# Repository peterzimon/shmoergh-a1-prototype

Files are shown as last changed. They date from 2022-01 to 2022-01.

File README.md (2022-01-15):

# Shmøergh A1 — Semi-modular analog monosynth

A1 is a fully analog semi-modular monosynth. I took the Minimoog as my main inspiration for its sound but of course the circuitry is nowhere comparable with it. The synth has a default hardwired patch inside, it has a couple of modulation sources and targets so we can consider it semi-modular. Everything is handmade by me at home. Most of the module circuits are based on very well-known schematics and a few of the circuits are original. 

a1

### Features
- Fat AF analog sound, fun
- Two voices with 3 waveshapes (saw, triangle, pulse) and additional noise and square suboscillator sound sources
- 24dB/oct diode low pass filter with self-resonance and dedicated envelope generator
- Triangle and square waveform LFO
- Mod matrix for overriding default patch
- Follows Eurorack standards: 10Vpp signal and modulation, 0-8V envelope levels
- All modules are designed and built on separate PCBs for reusability and experimenting

### What's in this repo?
You can find all the **KiCad 5** files (schematics and PCB design) of the synth here.

---

### License and disclaimer
All circuits, schematics, printed circuit board, panel design and associated data published within this project can be used for private use only. The author, host, and all people associated with these circuits disclaim any liability for damages should anyone be killed or injured while working on these projects, or projects based on these designs, or any other project or design presented in these schematics. The author, host, and all people associated with these circuits also disclaim any liability for projects, or projects based on these designs, or any other project or design presented on these web pages and any associated web pages when used in such a way as to infringe relevant government regulations and by-laws.

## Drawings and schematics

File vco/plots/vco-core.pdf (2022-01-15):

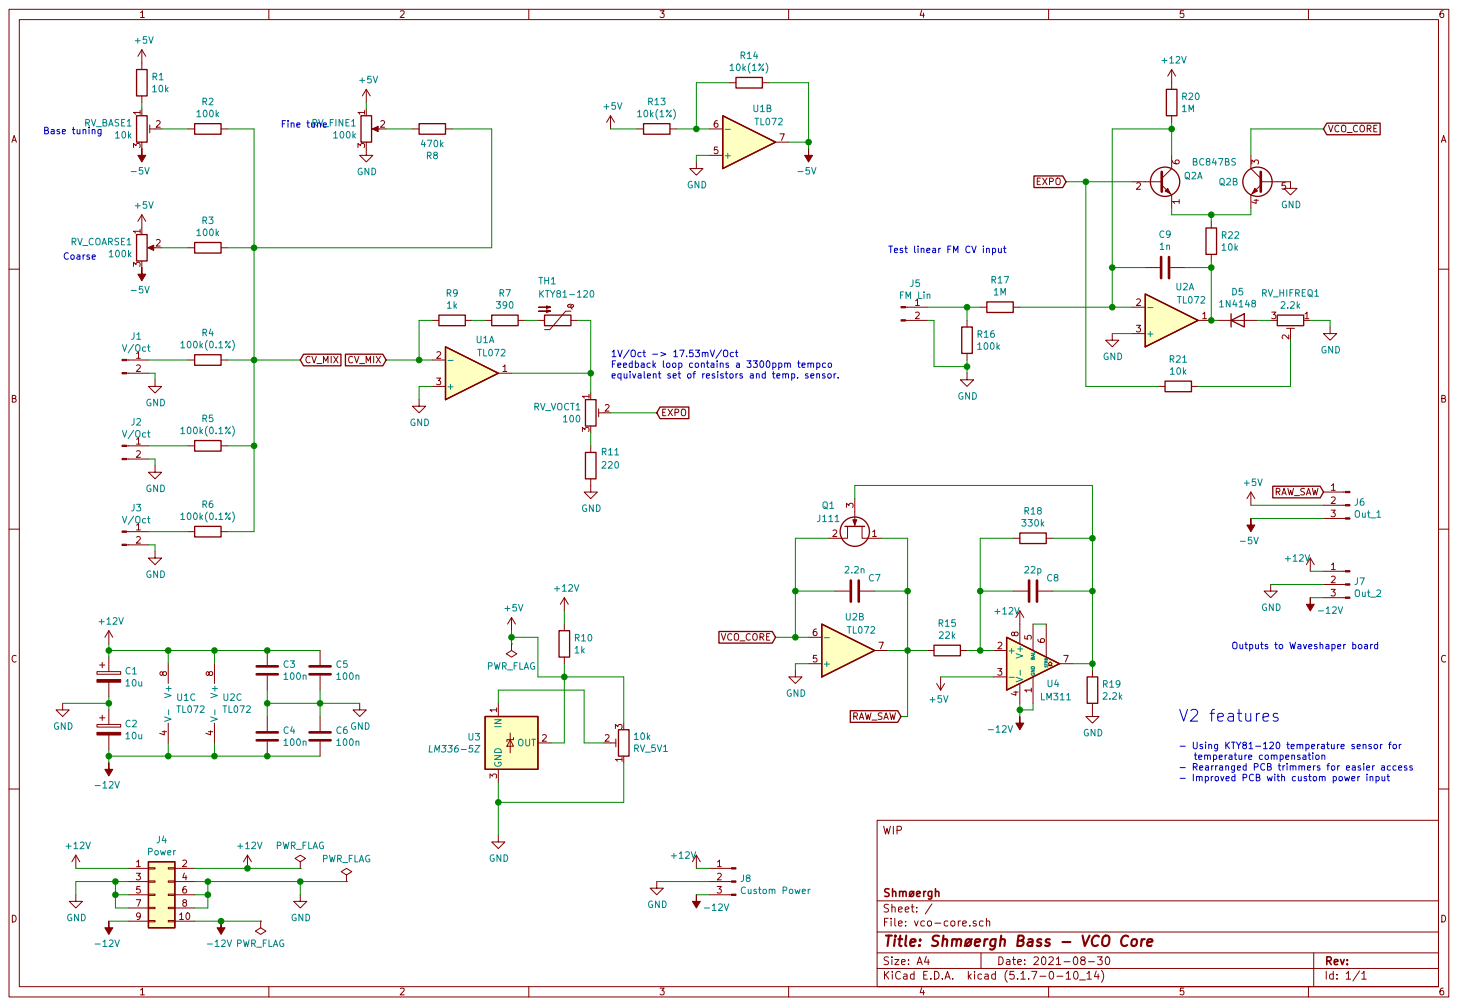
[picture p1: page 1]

1V/Oct -> 17.53mV/Oct Feedback loop contains a 3300ppm tempco
equivalent set of resistors and temp. sensor.
100 GND

- Using KTY81-120 temperature sensor for
temperature compensation
- Rearranged PCB trimmers for easier access
- Improved PCB with custom power input

File: vco-core.sch Sheet: / Shmøergh WIP

Id: 1/1 Title: Shmøergh Bass - VCO Core

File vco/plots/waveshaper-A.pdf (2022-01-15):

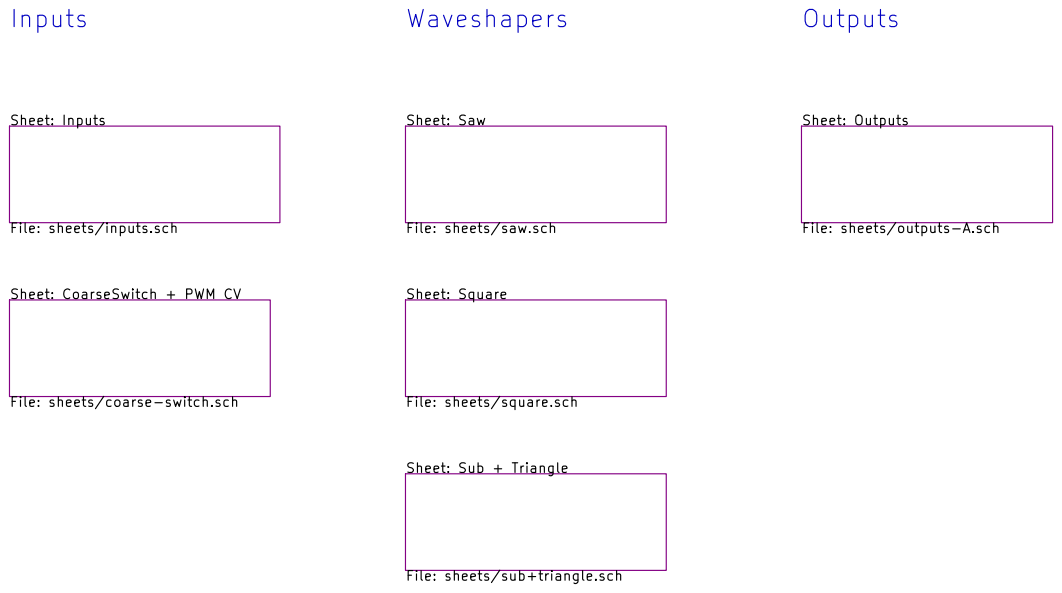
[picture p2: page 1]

File: sheets/coarse-switch.sch Sheet: Inputs

File: sheets/saw.sch Sheet: CoarseSwitch + PWM CV

File: sheets/inputs.sch

File: sheets/outputs-A.sch

File: sheets/square.sch

File: sheets/sub+triangle.sch

File: waveshaper-A.sch Sheet: / Shmøergh WIP

Id: 1/7 Title: Shmøergh Bass - VCO IO + Waveshaper

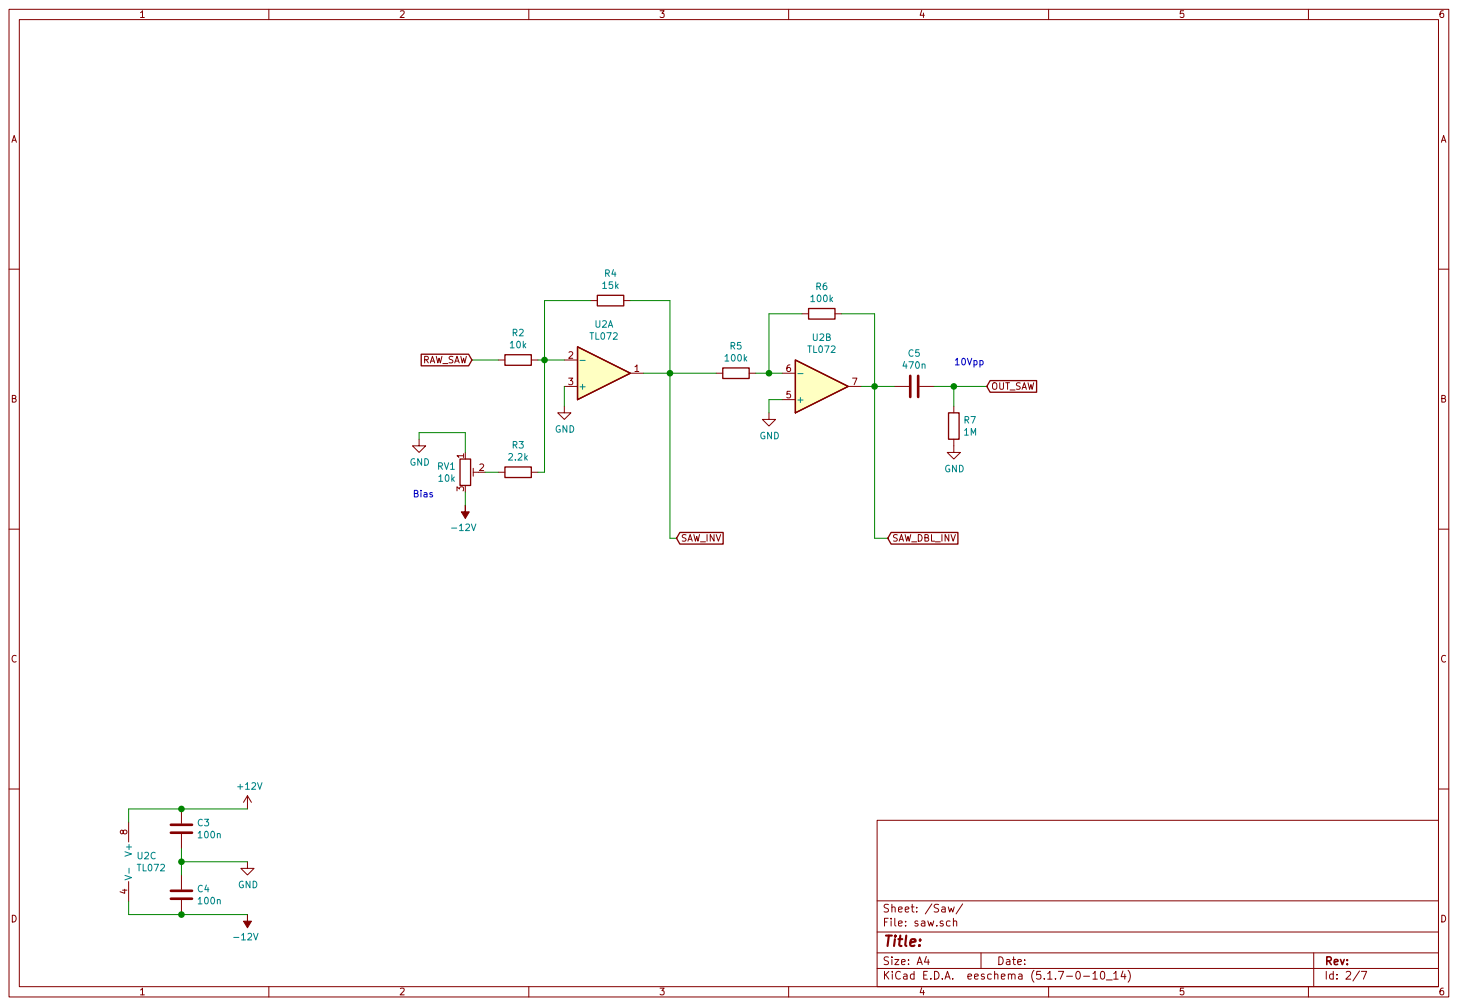
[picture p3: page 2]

Id: 2/7 Title: File: saw.sch Sheet: /Saw/

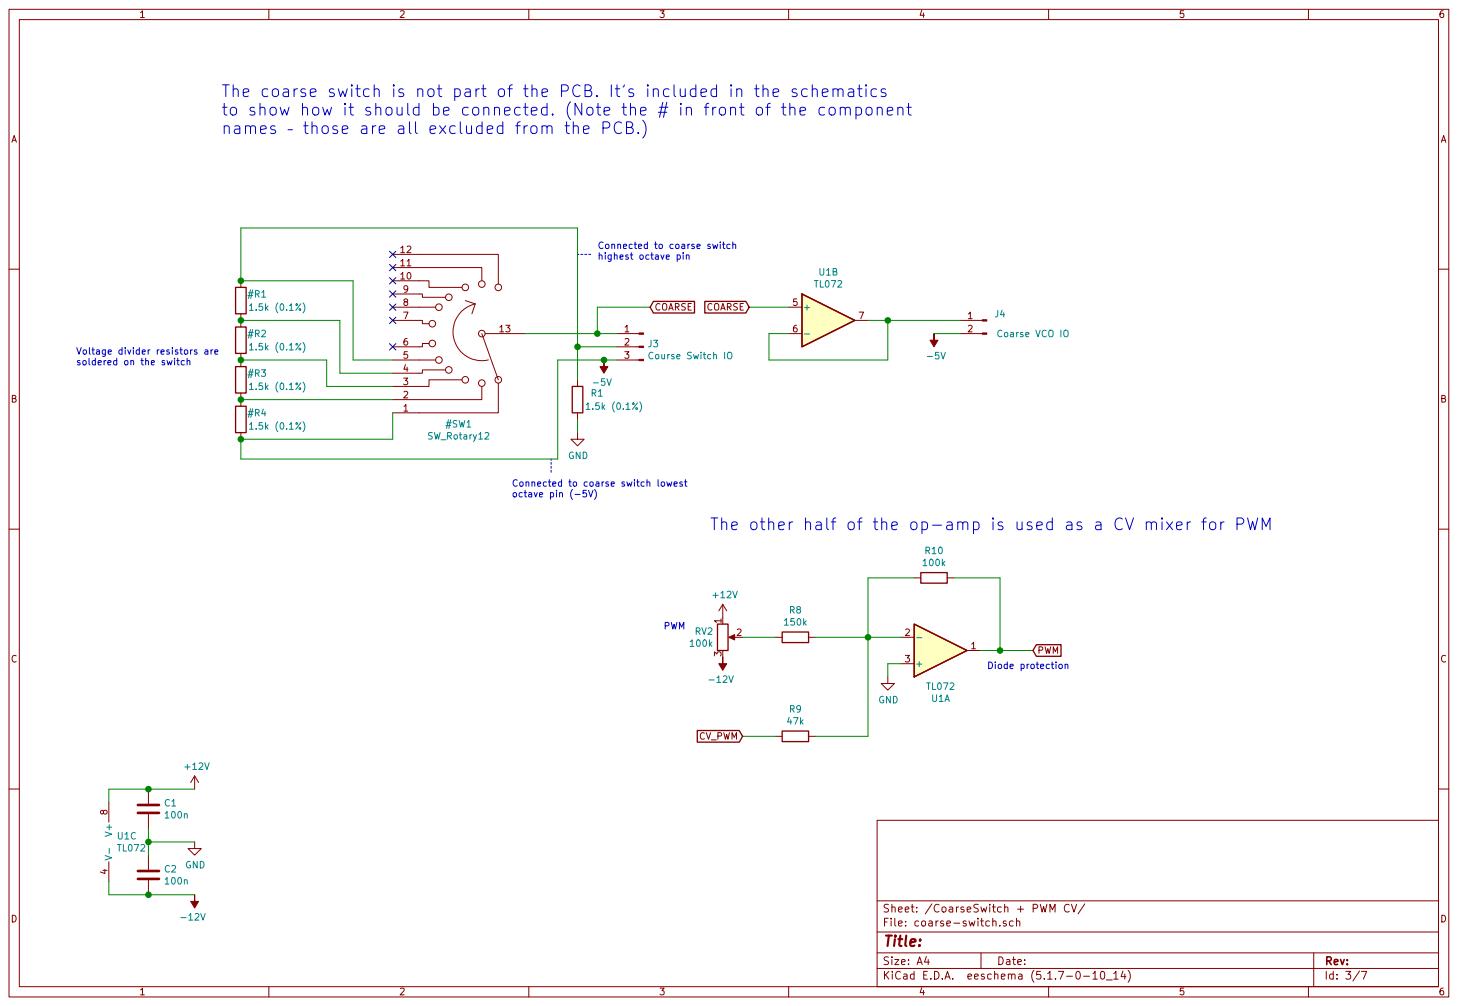
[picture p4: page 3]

The coarse switch is not part of the PCB. Its included in the schematics
to show how it should be connected. (Note the # in front of the component
names those are all excluded from the PCB.)

Id: 3/7 Title: File: coarse-switch.sch Sheet: /CoarseSwitch + PWM CV/

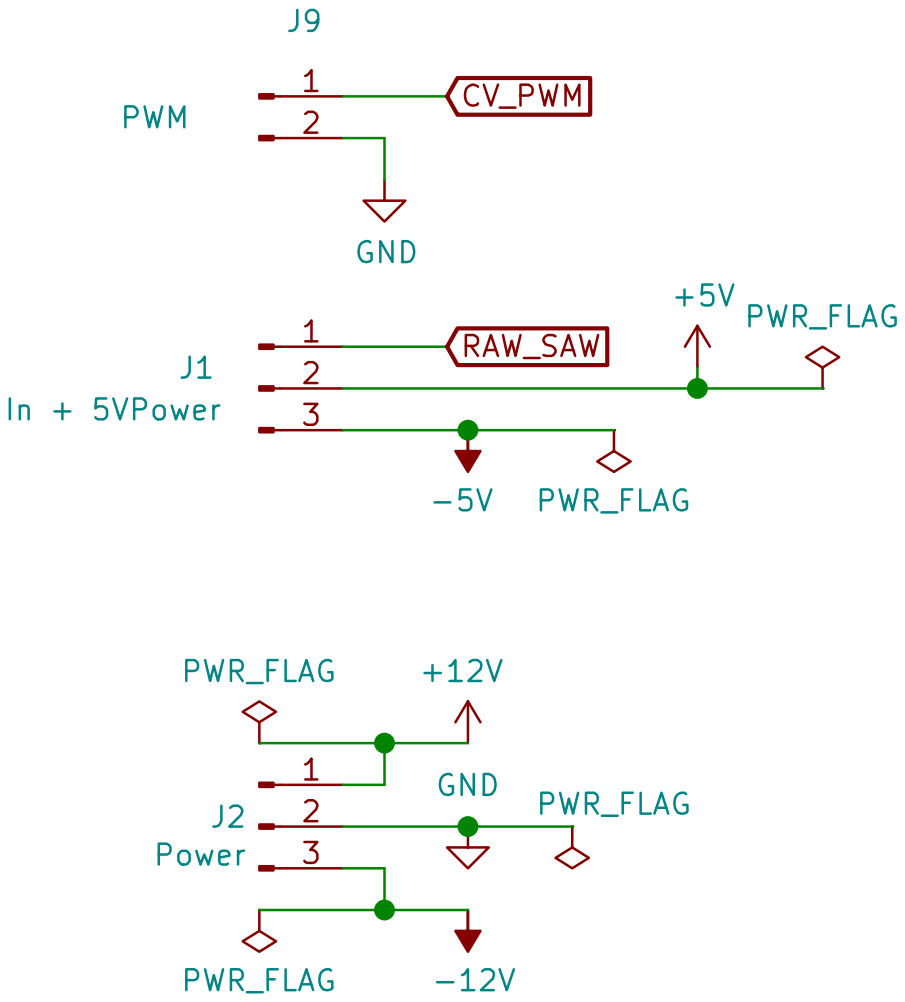
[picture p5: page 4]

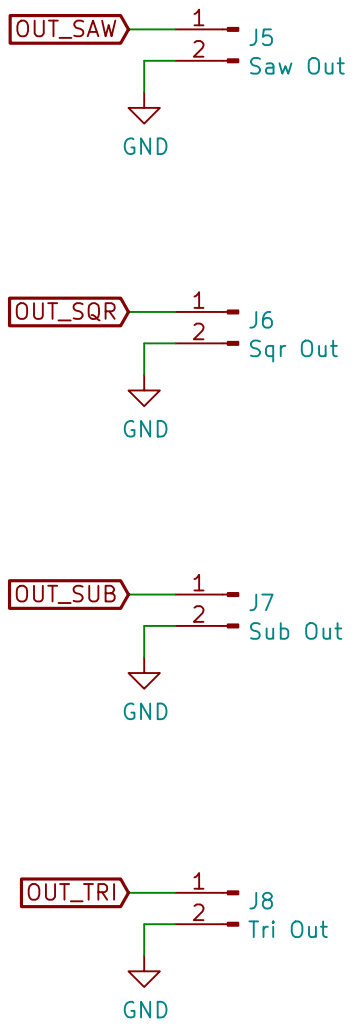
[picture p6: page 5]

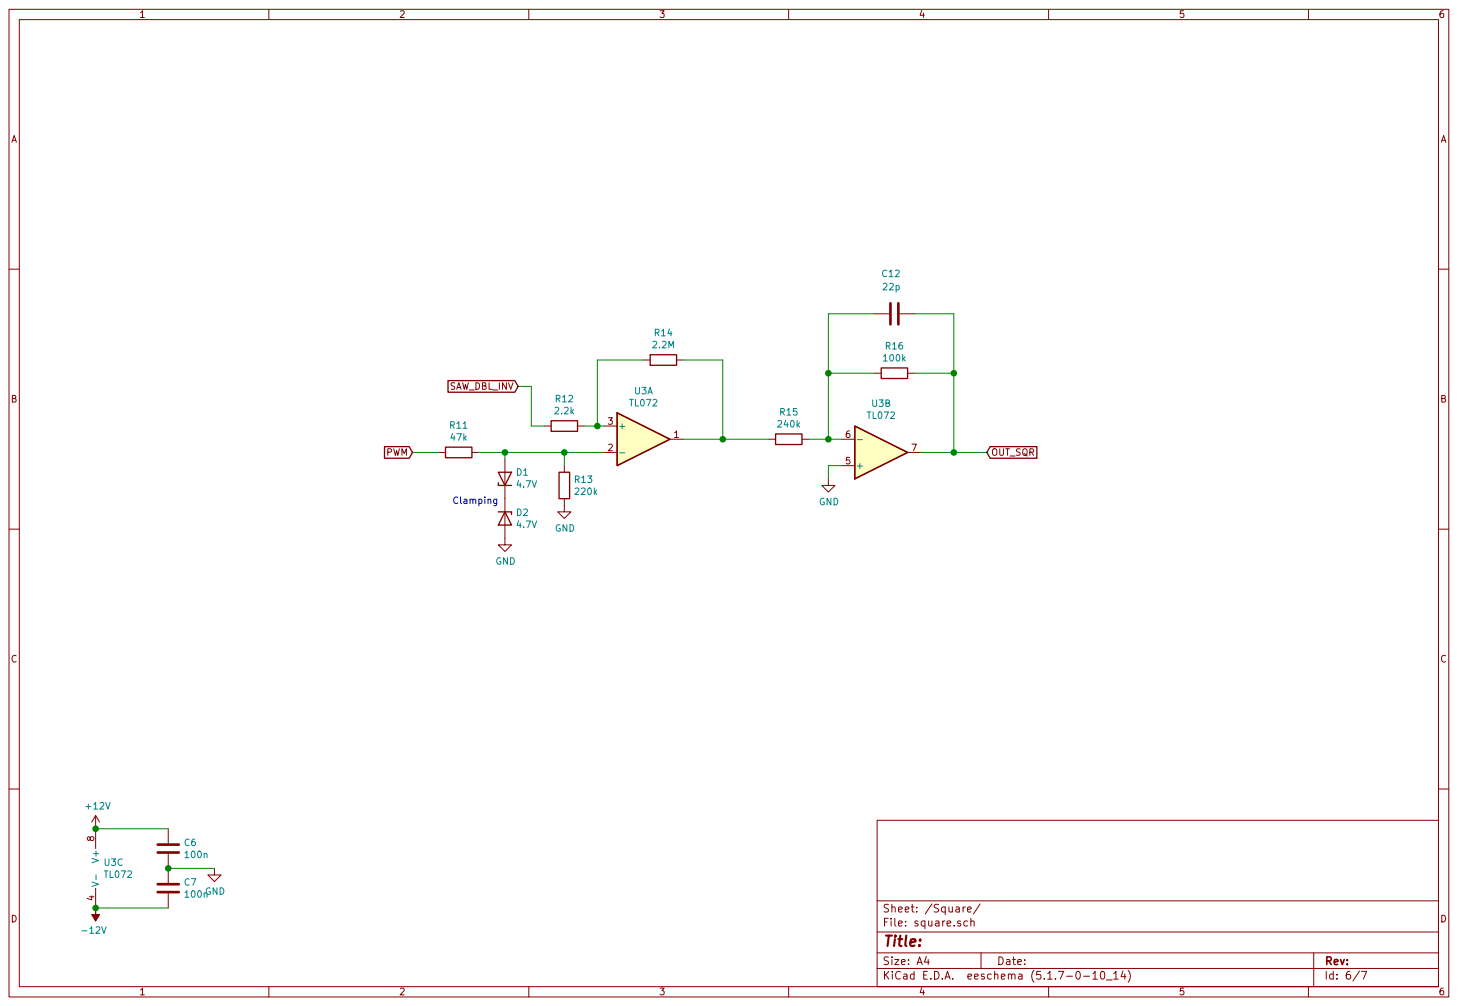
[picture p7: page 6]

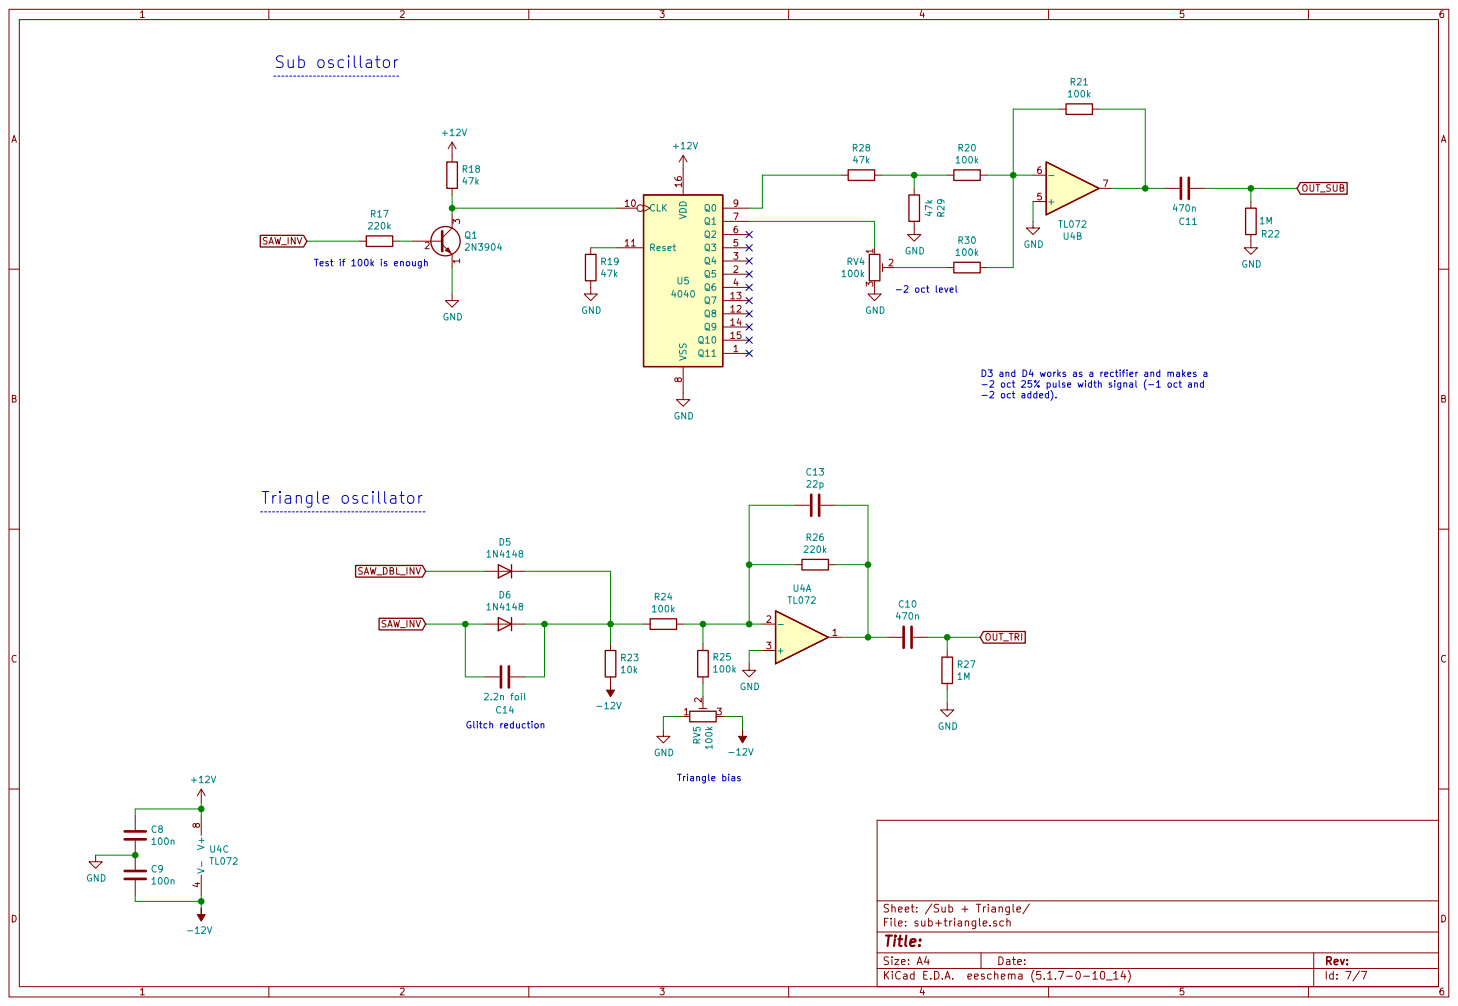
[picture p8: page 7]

Test if 100k is enough

Sheet: /Sub + Triangle/
File: sub+triangle.sch
Id: 7/7 Title:

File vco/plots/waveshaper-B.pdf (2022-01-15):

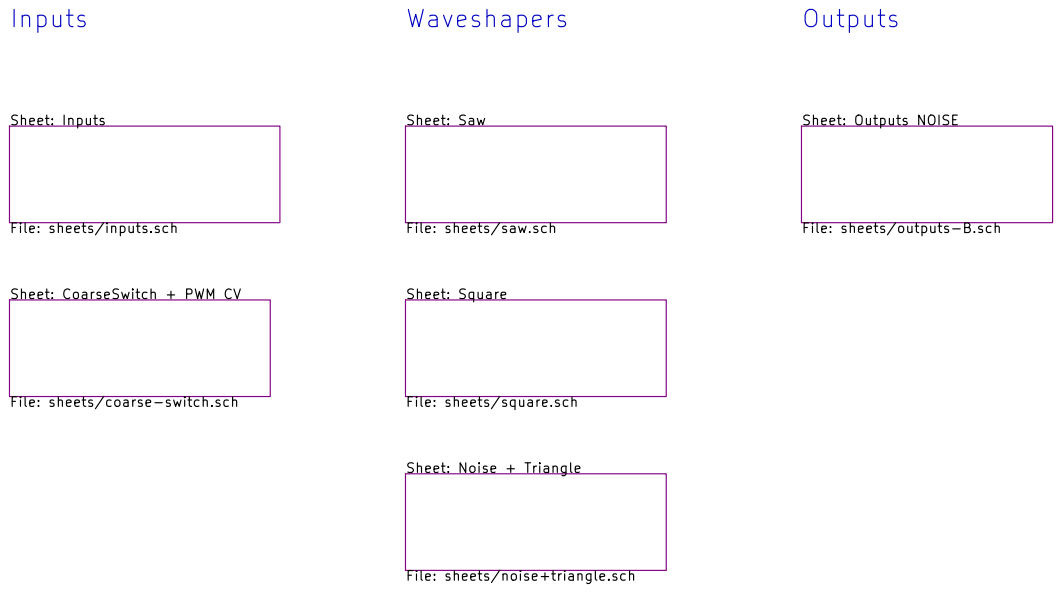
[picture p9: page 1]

File: sheets/coarse-switch.sch Sheet: Inputs

File: sheets/saw.sch Sheet: CoarseSwitch + PWM CV

File: sheets/inputs.sch

File: sheets/outputs-B.sch

File: sheets/square.sch

File: sheets/noise+triangle.sch

File: waveshaper-B.sch Sheet: / Shmøergh WIP

Id: 1/7 Title: Shmøergh Bass - VCO IO + Waveshaper


Id: 2/7 Title: File: saw.sch Sheet: /Saw/


The coarse switch is not part of the PCB. Its included in the schematics
to show how it should be connected. (Note the # in front of the component
names those are all excluded from the PCB.)

Id: 3/7 Title: File: coarse-switch.sch Sheet: /CoarseSwitch + PWM CV/


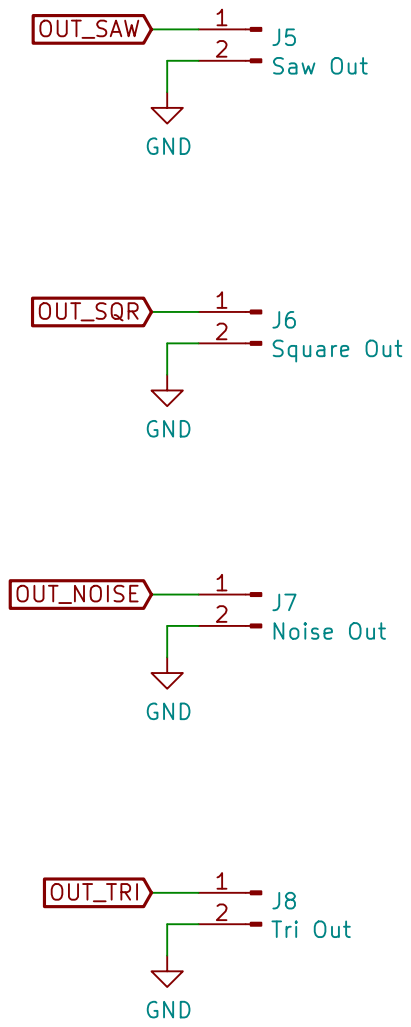
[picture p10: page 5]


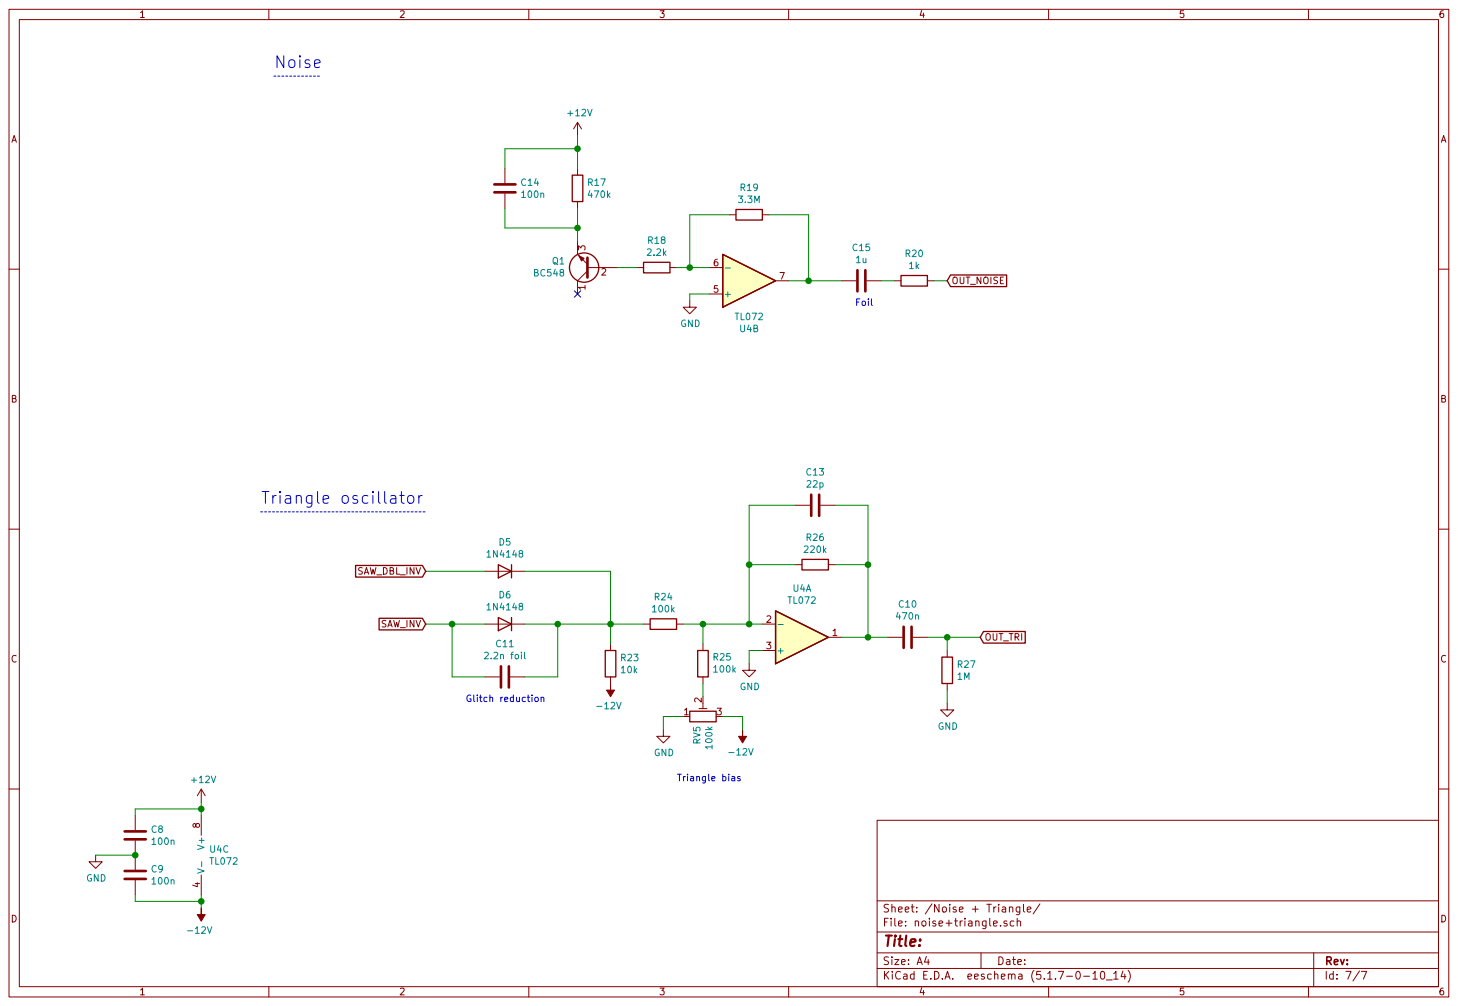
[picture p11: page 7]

File: noise+triangle.sch
Id: 7/7 Title:

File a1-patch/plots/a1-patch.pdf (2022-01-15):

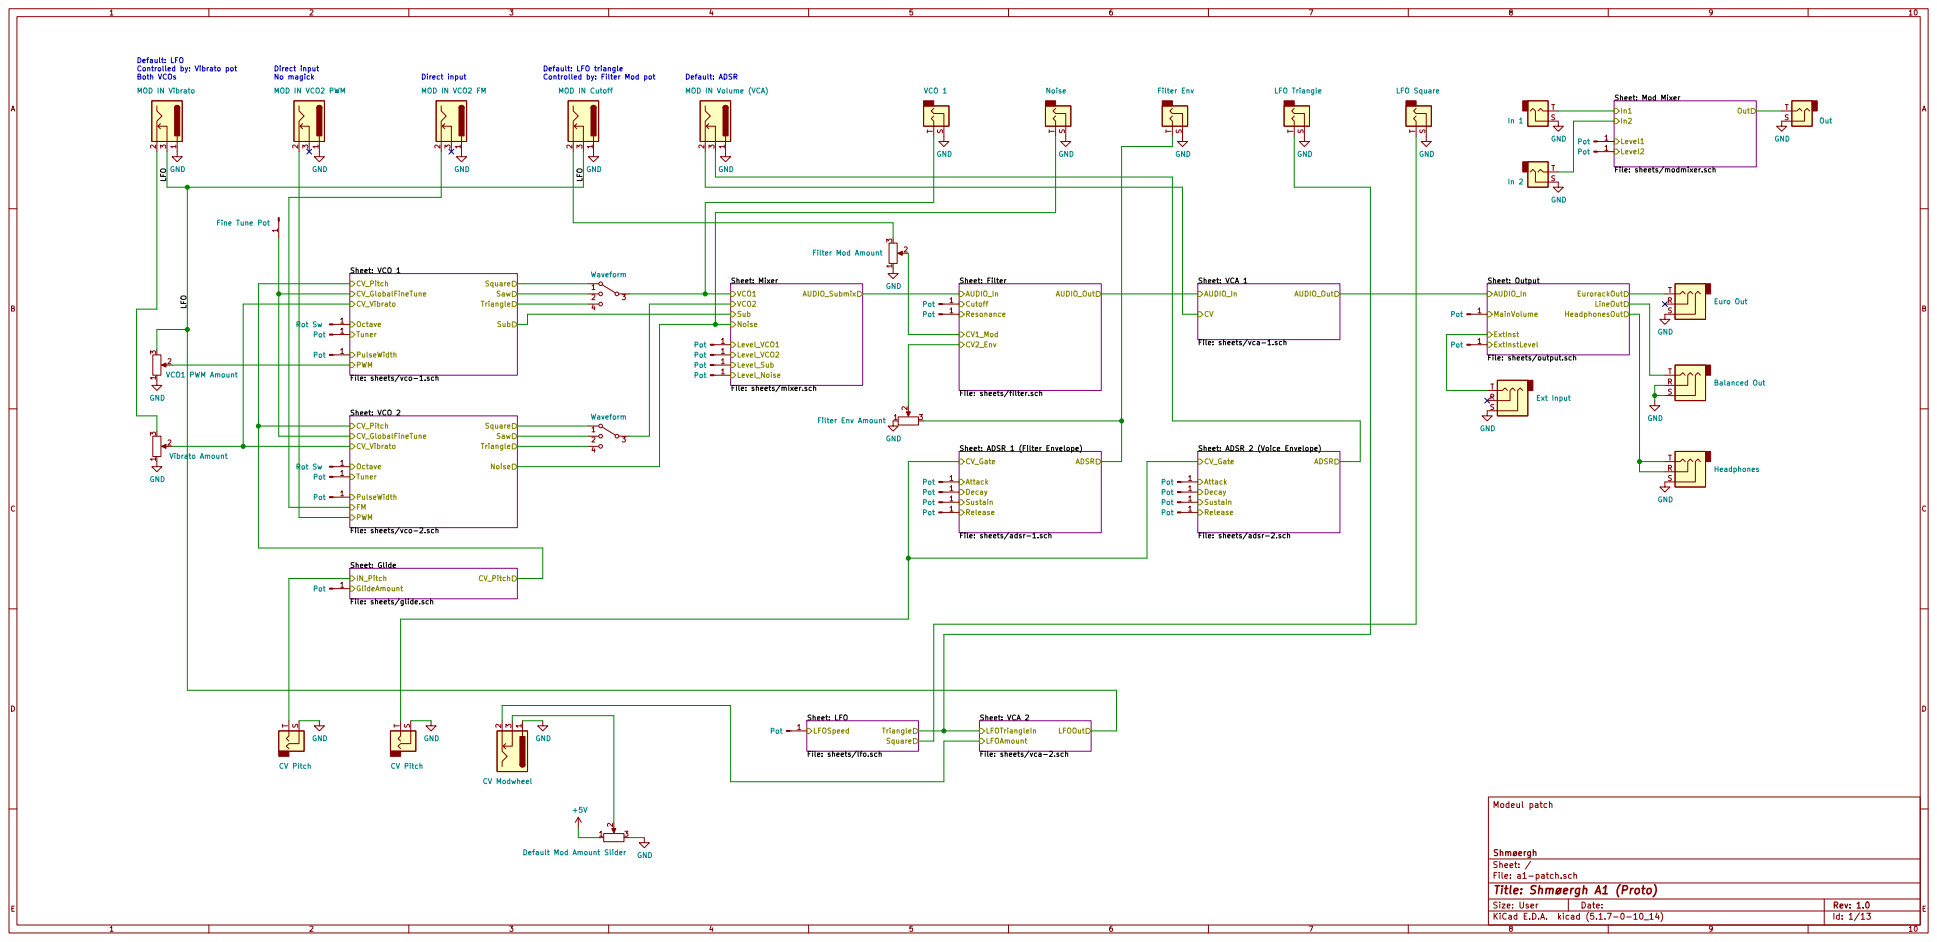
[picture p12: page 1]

Controlled by: Filter Mod pot

1 MOD IN Vibrato GND

1 MOD IN VCO2 FM LFO LFO LFO

1 MOD IN Cutoff GND GNDGND GND

1 MOD IN Volume (VCA) GND

Sheet: Mod Mixer File: sheets/modmixer.sch

3 VCO1 PWM Amount GND GND

3 Vibrato Amount GND GND

3 Filter Mod Amount GND GND GND

3 Filter Env Amount 1 Pot

Square Sheet: Glide File: sheets/glide.sch

Sheet: VCA 2 File: sheets/vca-2.sch

File: sheets/lfo.sch

3 Default Mod Amount Slider

File: a1-patch.sch Sheet: / Shmøergh

Id: 1/13 Title: Shmøergh A1 (Proto)

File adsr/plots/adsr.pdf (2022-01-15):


Id: 1/4 Title: File: adsr.sch Sheet: /


(c) Rene Schmitz - https://www.schmitzbits.de/adsr.html
File: adsr-1.sch Sheet: /ADSR 1/ Shmøergh


File: power.sch Sheet: /Power/
Id: 3/4 Title:


Id: 4/4 Title: File: adsr-2.sch Sheet: /ADSR 2/

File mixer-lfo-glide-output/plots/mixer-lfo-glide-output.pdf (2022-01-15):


Sheet: Power File: sheets/power.sch

File: sheets/inputs.sch

File: sheets/lfo.sch Sheet: Glide File: sheets/glide.sch

File: mixer-lfo-glide-output.sch Sheet: / Shmøergh

Id: 1/7 Title: Mixer + LFO + Glide


File: power.sch Sheet: /Power/
Id: 2/7 Title:


Level pots are wired on panel,
not present on PCB
#RV1 A50k GND

J22 Glide In GND GND


LFO Triangle (VCA) GND


Square narrow pulse width makes the
output center go off 0V. The 10u cap is
most probably not needed, as everything
(except for the external input) is AC
coupled already.

Id: 5/7 Title: File: mixer.sch Sheet: /Mixer/


Output level should be cca. 5V

Id: 6/7 Title: File: lfo.sch Sheet: /LFO/ C12


File: glide.sch Sheet: /Glide/ C15

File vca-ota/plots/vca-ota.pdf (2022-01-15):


connected to modwheel of keyboard.

File: vca-ota.sch Sheet: / Shmøergh A1


File: power.sch Sheet: /Power/
Id: 2/4 Title:


CV from the Mod mixer. This can
either be +/-5V (e.g. LFO or VCO
output) or 0-8V (filter ADSR).
Negative values shouldnt be an
issue because Q1 would be closed
in that case, so the input should be

Id: 3/4 Title: File: vca-1.sch Sheet: /OTA-VCA-1/


or via the modwheel of a controller. LFO VCA

Jack as switch here to enable direct modwheel connection from controller. Transistors reverse bias safety diode

The purpose of this VCA is to be able to controll the
LFO amount via either the mod slider pot on the synth

in case of negative

This is the slider pot on the
frontpanel of the synth. Its
the same purpose as the modwheel on controllers.

Safety resistor, max Iabc = 12V / 6.8k = 1.76mA
(in case transistors collector voltage = 12V)

IOut(pp) = (q/2kT) * Iabc * Vin = 19.2 * 500uA * 61.6mV

Id: 4/4 Title: File: vca-2.sch Sheet: /OTA-VCA-2/

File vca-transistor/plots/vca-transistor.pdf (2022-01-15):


connected to modwheel of keyboard.

File: vca-transistor.sch Sheet: / Shmøergh A1


VCA for the main output. Chain:
VCO > Mixer > Filter > VCA (controlled by ADSR 1) > Out stage

transistors +/-5V Coming from the mod matrix 0-8V Only for VCA 1

Should be around 5.6k Matched

Id: 2/4 Title: File: vca-1.sch Sheet: /VCA-1/


File: power.sch Sheet: /Power/
Id: 3/4 Title:


The purpose of this VCA is to let the modwheel
control the amount of global LFO. Alternatively
theres a slide pot that can be used instead of

transistors Jack as switch here to enable modwheel connection Only for VCA 2

Id: 4/4 Title: File: vca-2.sch Sheet: /VCA-2/

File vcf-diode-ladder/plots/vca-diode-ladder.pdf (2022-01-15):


To be improved: the resonance path
picks up a lot of hum, especially if

RV_RESONANCE pot is connected via wires. To be improved: passive CV mixer to active

File: vca-diode-ladder.sch Sheet: / WIP

Id: 1/1 Title: Schmøergh Analog - Diode Ladder VCF

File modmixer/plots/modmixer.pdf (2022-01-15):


File: modmixer.sch Sheet: / Shmøergh

Id: 1/1 Title: ModMatrix Utilities

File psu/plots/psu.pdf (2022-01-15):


Id: 1/1 Title: Shmøergh Bass PSU


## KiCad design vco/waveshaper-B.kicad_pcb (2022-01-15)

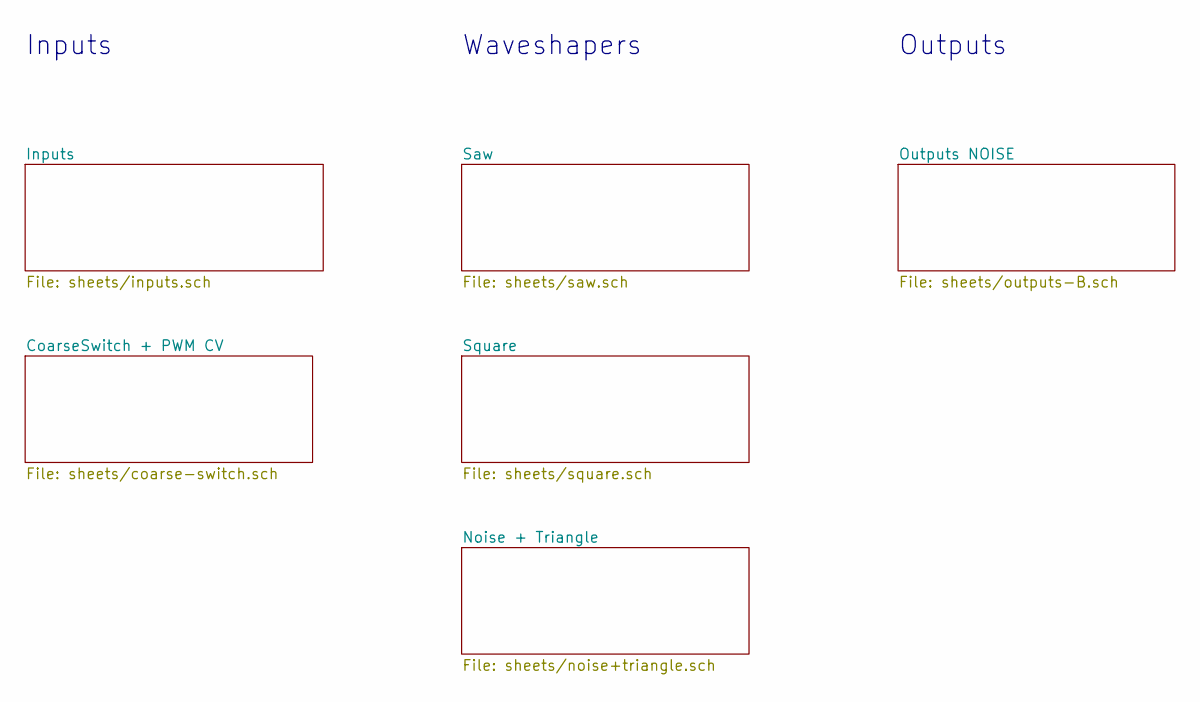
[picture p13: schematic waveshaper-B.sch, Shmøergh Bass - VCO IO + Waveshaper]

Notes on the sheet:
Inputs
Waveshapers
Outputs

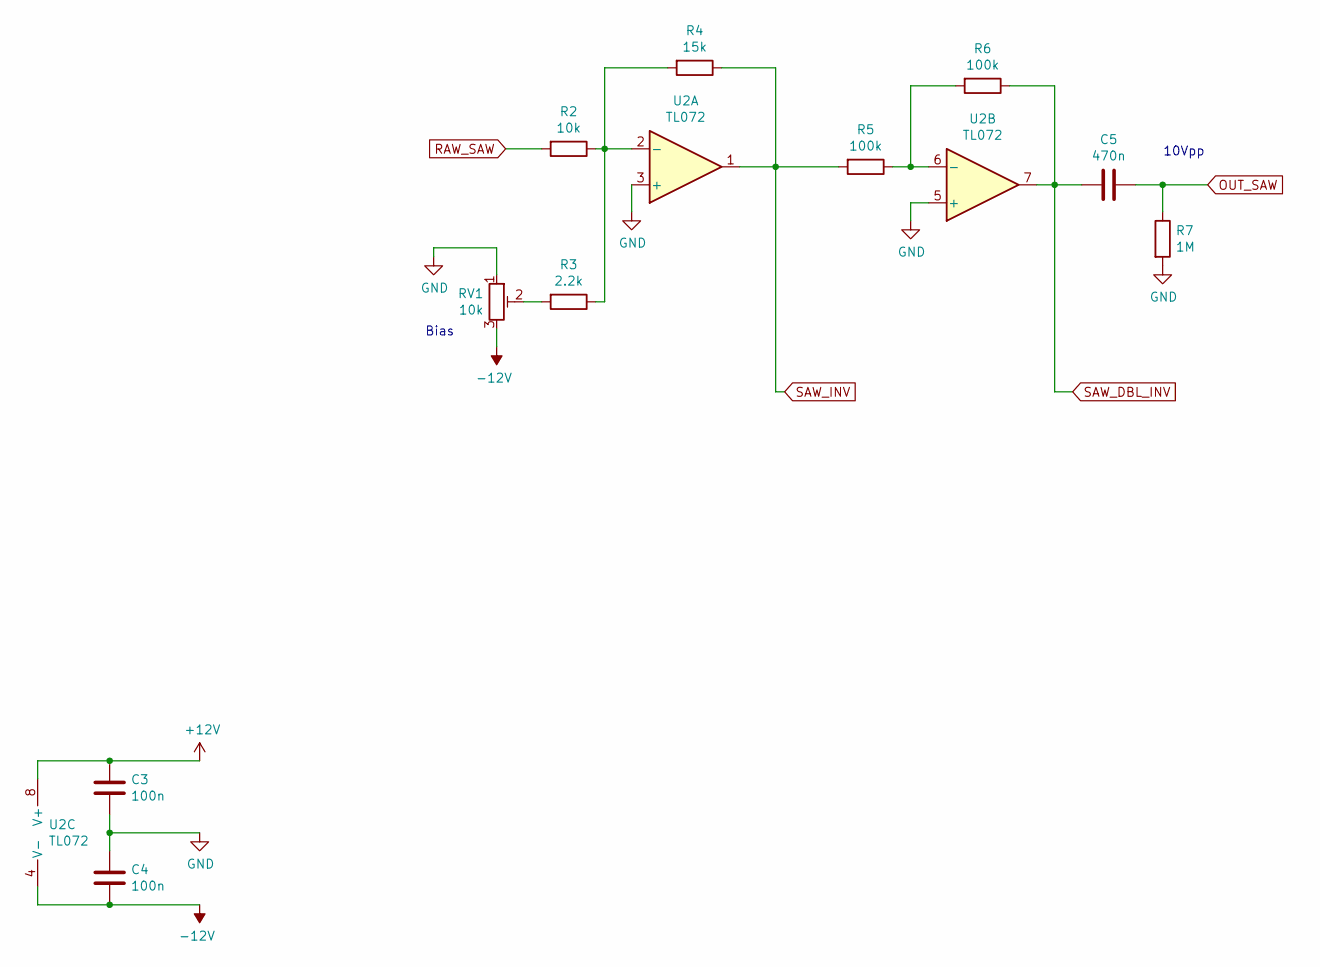
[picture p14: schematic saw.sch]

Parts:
C3, C4: 100n; C_Disc_D5.0mm_W2.5mm_P2.50mm
C5: 470n; C_Disc_D5.0mm_W2.5mm_P2.50mm
R2: 10k; R_Axial_Vertical
R3: 2.2k; R_Axial_Vertical
R4: 15k; R_Axial_Vertical
R5, R6: 100k; R_Axial_Vertical
R7: 1M; R_Axial_Vertical
RV1: 10k; PinOut_01x03
U2: TL072; DIP-8_W7.62mm

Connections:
+12V: C3.1, U2.8 (V+); also elsewhere on the board
-12V: C4.2, RV1.3, U2.4 (V-); also elsewhere on the board
unnamed: R2.1, R3.1, R4.2, U2.2 (-)
unnamed: R3.2, RV1.2
unnamed: R5.1, R6.2, U2.6 (-)
OUT_SAW: C5.1, R7.1; also elsewhere on the board
RAW_SAW: R2.2; also elsewhere on the board
SAW_DBL_INV: C5.2, R6.1, U2.7; also elsewhere on the board
SAW_INV: R4.1, R5.2, U2.1; also elsewhere on the board

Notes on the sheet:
Bias
10Vpp

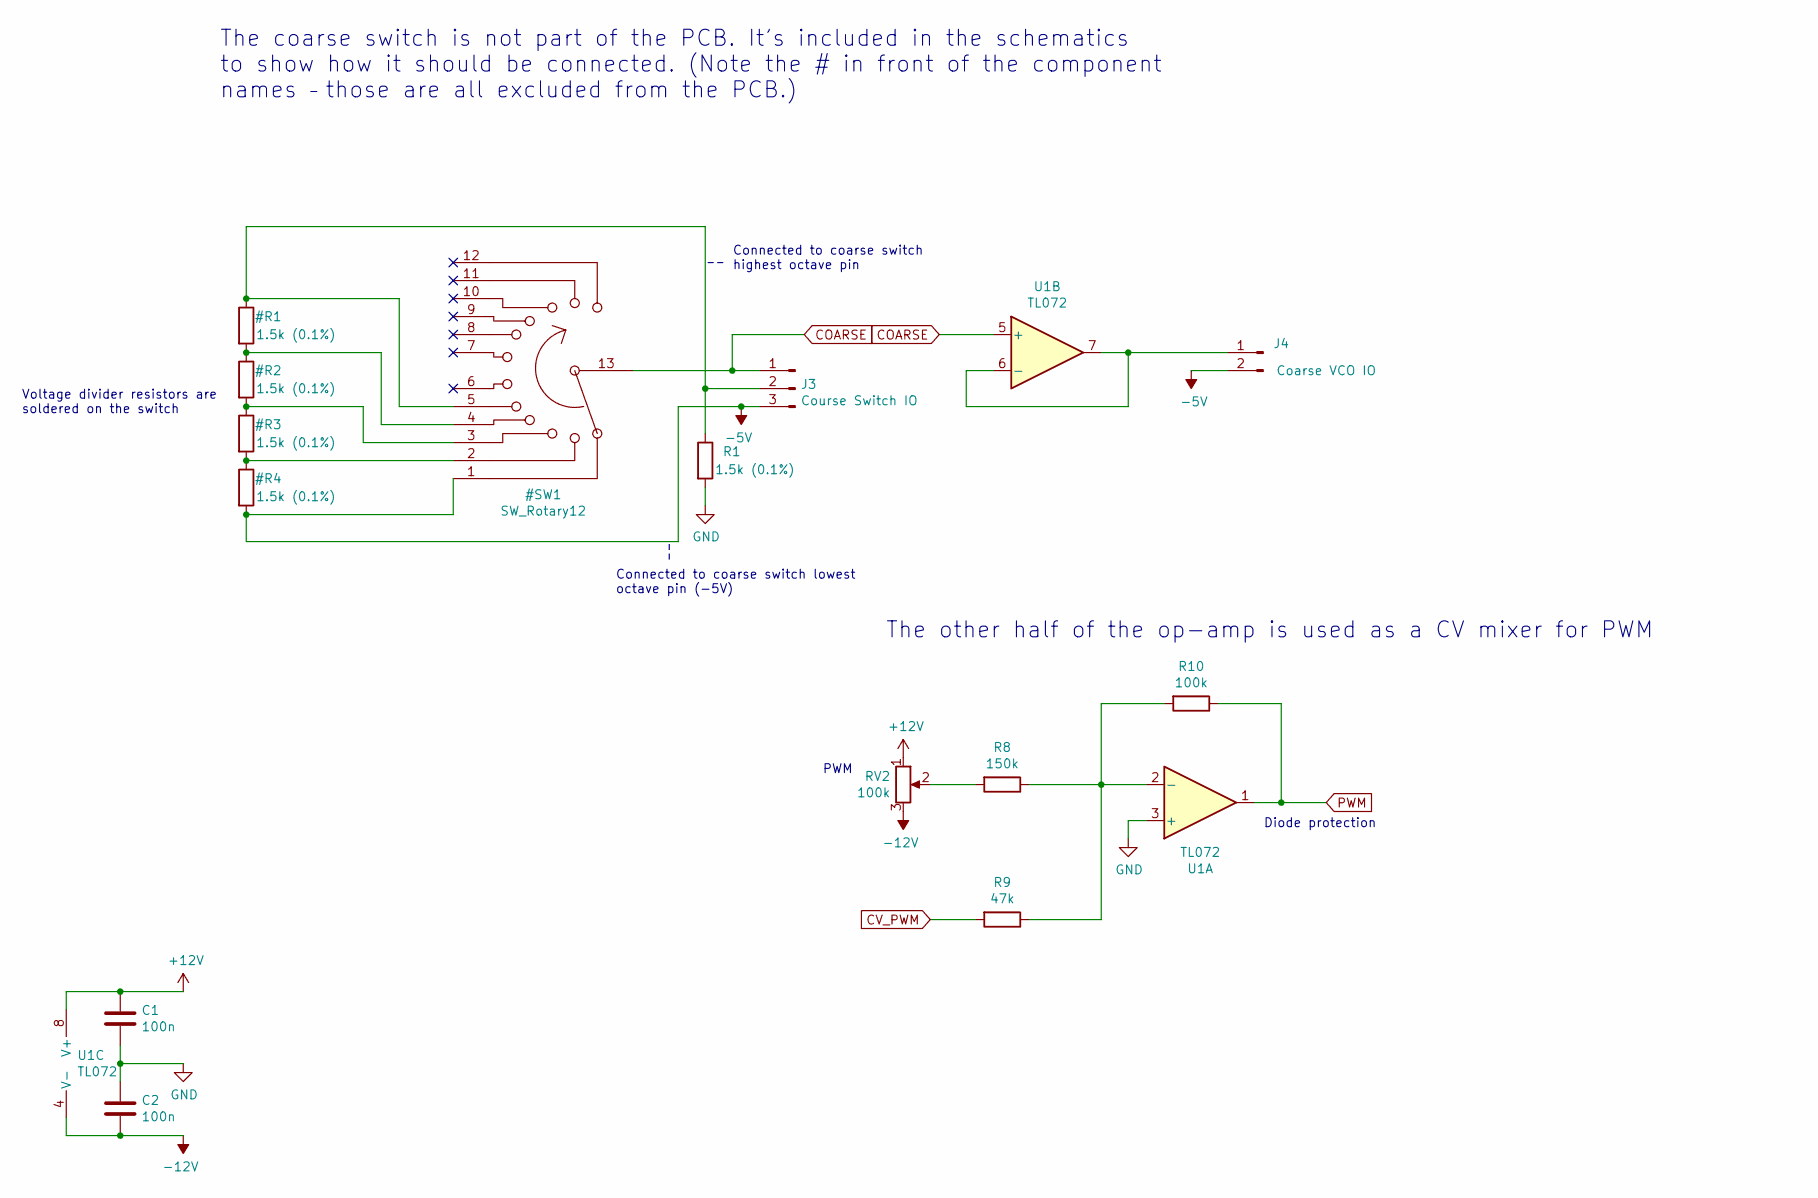
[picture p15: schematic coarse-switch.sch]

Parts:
C1, C2: 100n; C_Disc_D5.0mm_W2.5mm_P2.50mm
J3: Course Switch IO; NSL25_01x03_Vertical
J4: Coarse VCO IO; NSL25_01x02_Vertical
R1: 1.5k (0.1%); R_Axial_Vertical
R8: 150k; R_Axial_Vertical
R9: 47k; R_Axial_Vertical
R10: 100k; R_Axial_Vertical
RV2: 100k; NSL25_01x03_Vertical
U1: TL072; DIP-8_W7.62mm

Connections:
+12V: C1.1, RV2.1, U1.8 (V+); also elsewhere on the board
-12V: C2.2, RV2.3, U1.4 (V-); also elsewhere on the board
CV_PWM: R9.2; also elsewhere on the board
unnamed: J4.1, U1.6 (-), U1.7
unnamed: R8.2, RV2.2

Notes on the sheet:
Connected to coarse switch lowest octave pin (-5V)
Voltage divider resistors are soldered on the switch
The coarse switch is not part of the PCB. It’s included in the schematics to show how it should be connected. (Note the # in front of the component names – those are all excluded from the PCB.)
Diode protection
The other half of the op-amp is used as a CV mixer for PWM
PWM
Connected to coarse switch highest octave pin

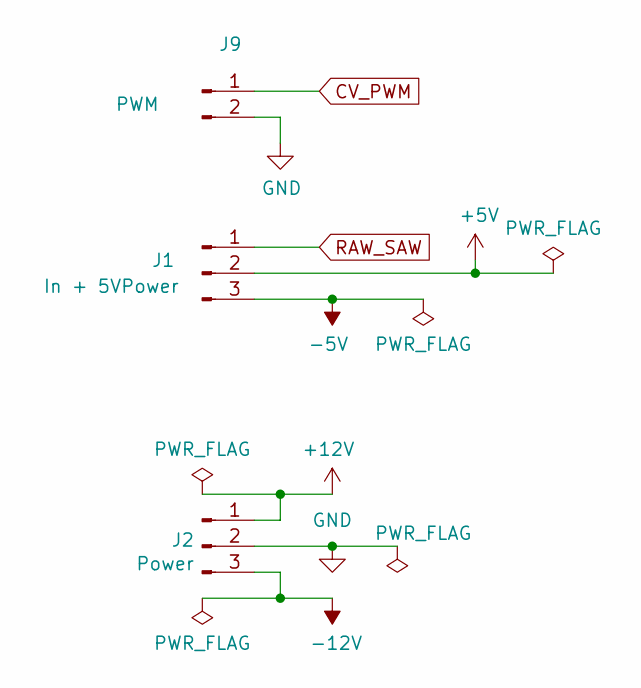
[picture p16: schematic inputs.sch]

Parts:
J1: In + 5VPower; NSL25_01x03_Vertical
J2: Power; NSL25_01x03_Vertical
J9: PWM; NSL25_01x02_Vertical

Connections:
+5V: J1.2
+12V: J2.1; also elsewhere on the board
-12V: J2.3; also elsewhere on the board
CV_PWM: J9.1; also elsewhere on the board
RAW_SAW: J1.1; also elsewhere on the board

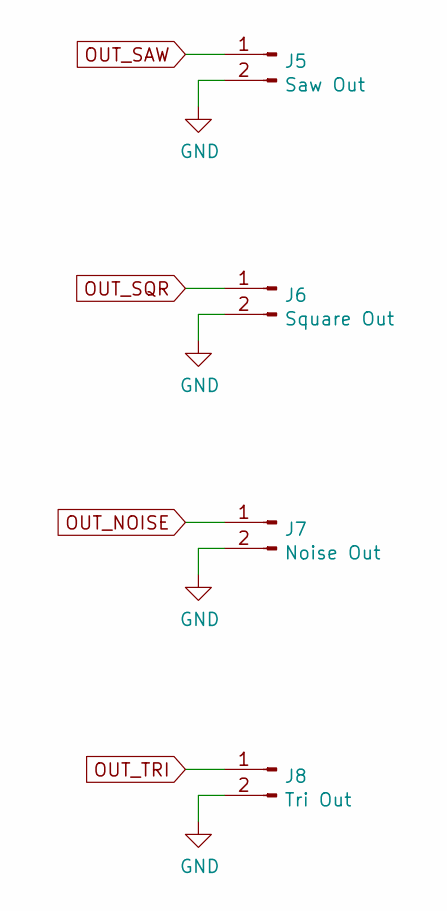
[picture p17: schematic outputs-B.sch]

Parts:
J5: Saw Out; NSL25_01x02_Vertical
J6: Square Out; NSL25_01x02_Vertical
J7: Noise Out; NSL25_01x02_Vertical
J8: Tri Out; NSL25_01x02_Vertical

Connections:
OUT_NOISE: J7.1; also elsewhere on the board
OUT_SAW: J5.1; also elsewhere on the board
OUT_SQR: J6.1; also elsewhere on the board
OUT_TRI: J8.1; also elsewhere on the board

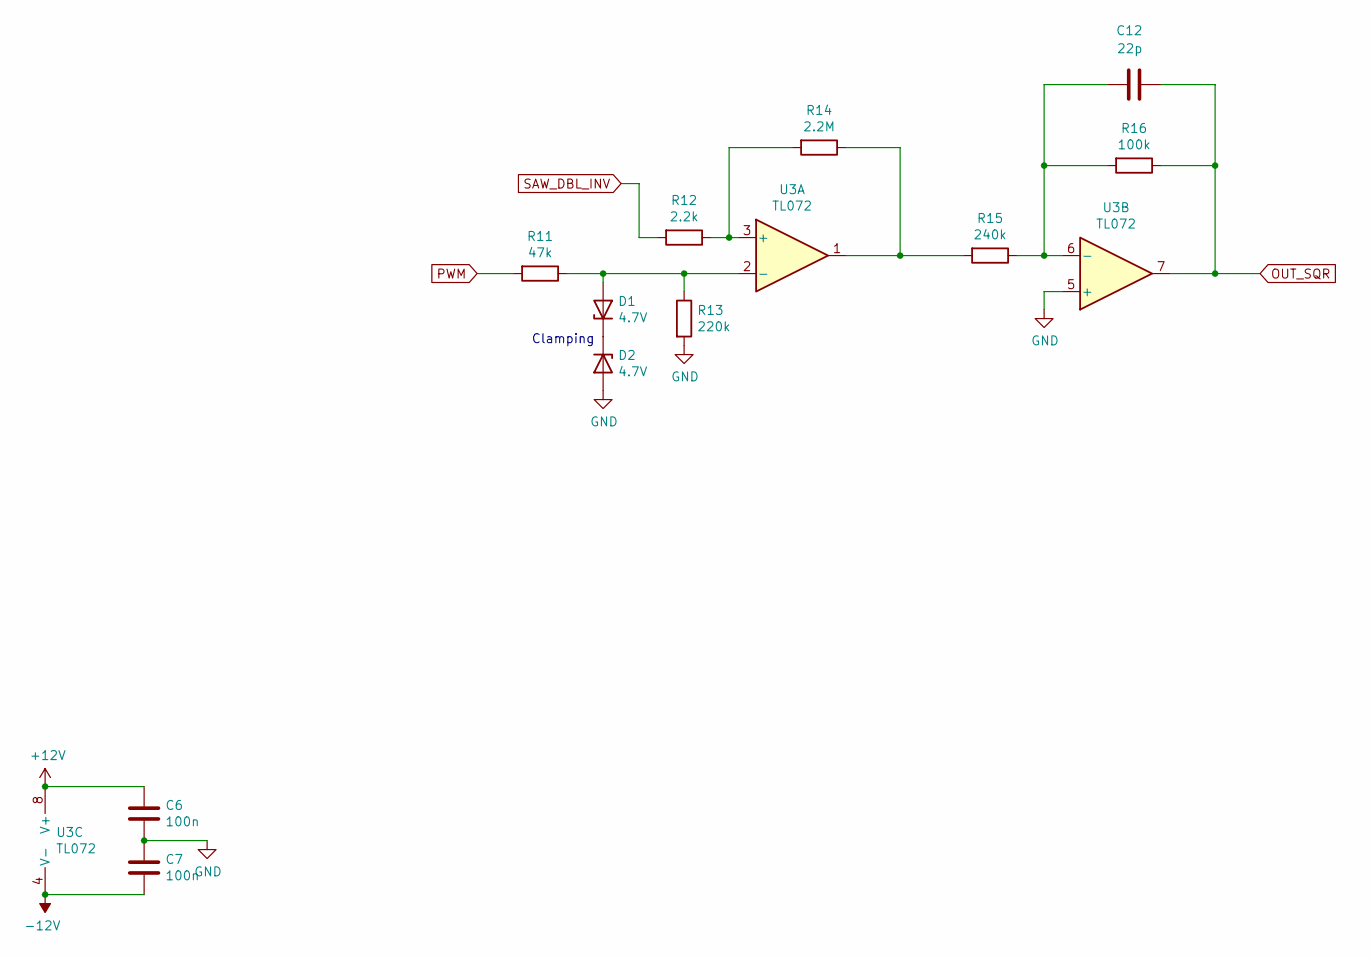
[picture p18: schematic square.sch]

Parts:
C6, C7: 100n; C_Disc_D5.0mm_W2.5mm_P2.50mm
C12: 22p; C_Disc_D5.0mm_W2.5mm_P2.50mm
D1, D2: 4.7V; D_Axial-Vertical
R11: 47k; R_Axial_Vertical
R12: 2.2k; R_Axial_Vertical
R13: 220k; R_Axial_Vertical
R14: 2.2M; R_Axial_Vertical
R15: 240k; R_Axial_Vertical
R16: 100k; R_Axial_Vertical
U3: TL072; DIP-8_W7.62mm

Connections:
+12V: C6.1, U3.8 (V+); also elsewhere on the board
-12V: C7.2, U3.4 (V-); also elsewhere on the board
unnamed: C12.1, R15.1, R16.2, U3.6 (-)
unnamed: D1.1 (K), D2.1 (K)
unnamed: D1.2 (A), R11.1, R13.1, U3.2 (-)
unnamed: R12.1, R14.2, U3.3 (+)
unnamed: R14.1, R15.2, U3.1
OUT_SQR: C12.2, R16.1, U3.7; also elsewhere on the board
SAW_DBL_INV: R12.2; also elsewhere on the board

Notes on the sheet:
Clamping

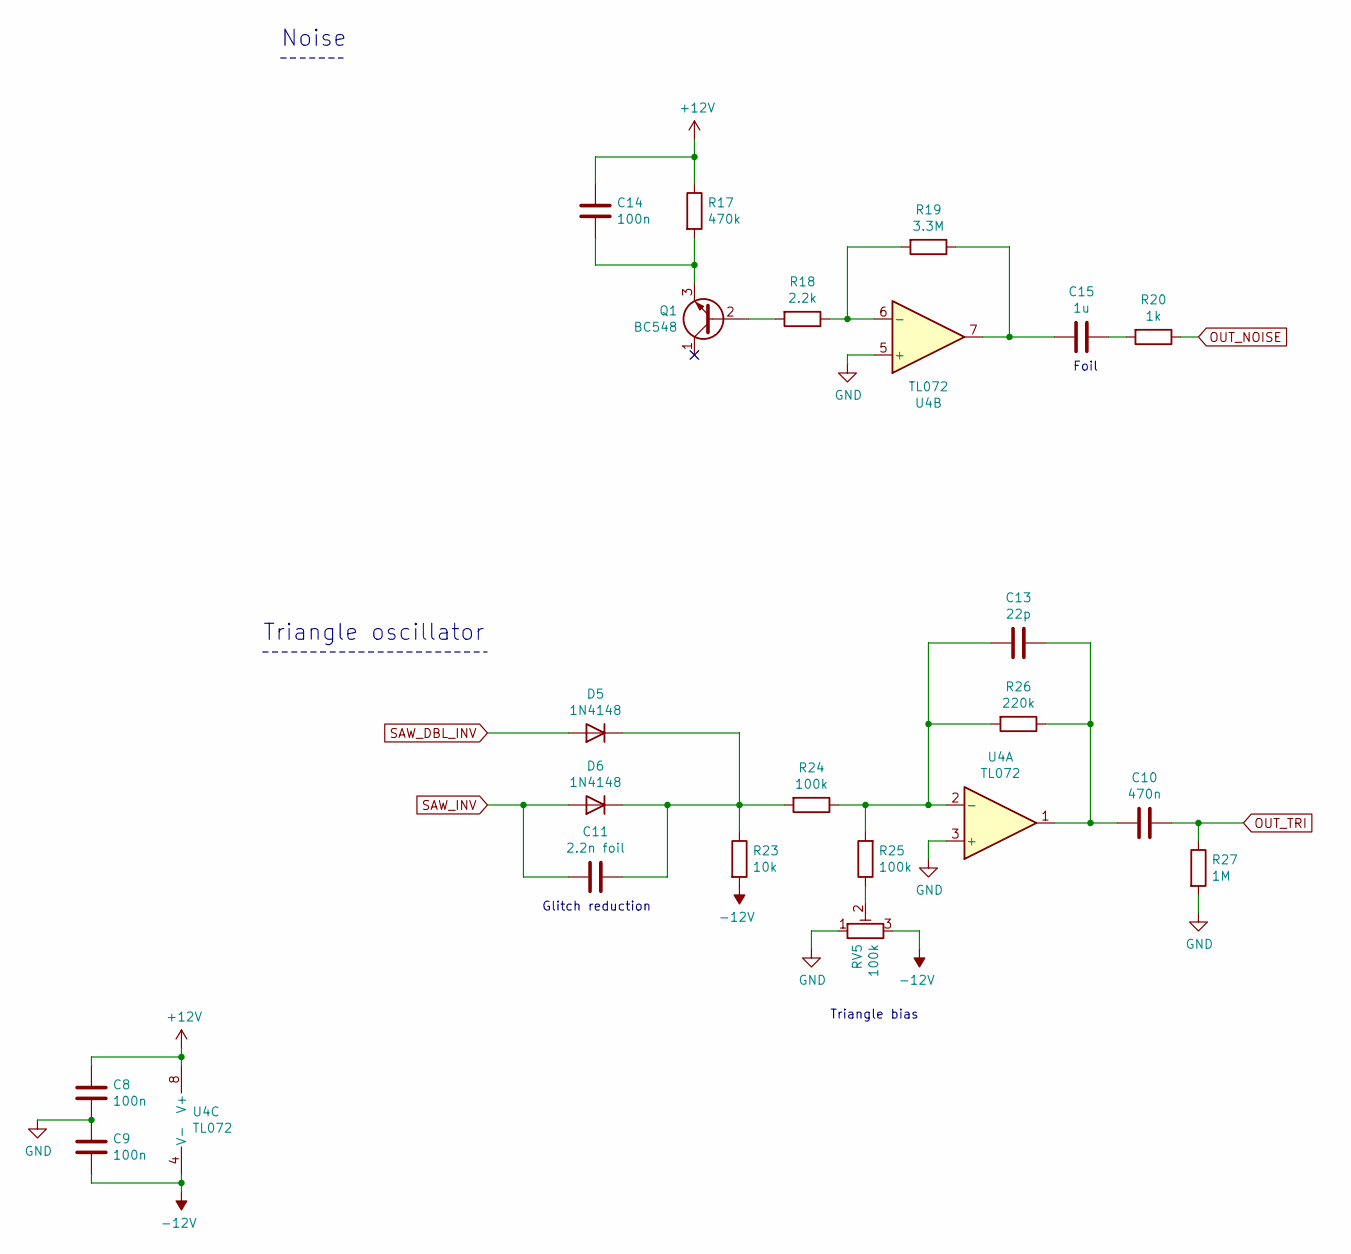
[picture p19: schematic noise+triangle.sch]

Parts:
C8, C9, C14: 100n; C_Disc_D5.0mm_W2.5mm_P2.50mm
C10: 470n; C_Disc_D5.0mm_W2.5mm_P2.50mm
C11: 2.2n foil; C_Foil_P5.48mm
C13: 22p; C_Disc_D5.0mm_W2.5mm_P2.50mm
C15: 1u; C_Foil_P5.48mm
D5, D6: 1N4148; D_Axial
Q1: BC548; TO-92_Inline
R17: 470k; R_Axial_Vertical
R18: 2.2k; R_Axial_Vertical
R19: 3.3M; R_Axial_Vertical
R20: 1k; R_Axial_Vertical
R23: 10k; R_Axial_DIN0207_L6.3mm_D2.5mm_P7.62mm_Horizontal
R24, R25: 100k; R_Axial_DIN0207_L6.3mm_D2.5mm_P7.62mm_Horizontal
R26: 220k; R_Axial_Vertical
R27: 1M; R_Axial_Vertical
RV5: 100k; PinOut_01x03
U4: TL072; DIP-8_W7.62mm

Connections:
+12V: C8.1, C14.1, R17.1, U4.8 (V+); also elsewhere on the board
-12V: C9.2, R23.2, RV5.3, U4.4 (V-); also elsewhere on the board
unnamed: C10.2, C13.1, R26.1, U4.1
unnamed: C11.1, D5.1 (K), D6.1 (K), R23.1, R24.2
unnamed: C13.2, R24.1, R25.2, R26.2, U4.2 (-)
unnamed: C14.2, Q1.3 (E), R17.2
unnamed: C15.1, R20.2
unnamed: C15.2, R19.1, U4.7
unnamed: Q1.2 (B), R18.2
unnamed: R18.1, R19.2, U4.6 (-)
unnamed: R25.1, RV5.2
OUT_NOISE: R20.1; also elsewhere on the board
OUT_TRI: C10.1, R27.1; also elsewhere on the board
SAW_DBL_INV: D5.2 (A); also elsewhere on the board
SAW_INV: C11.2, D6.2 (A); also elsewhere on the board

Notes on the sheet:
Noise
Triangle oscillator
Triangle bias
Glitch reduction
Foil

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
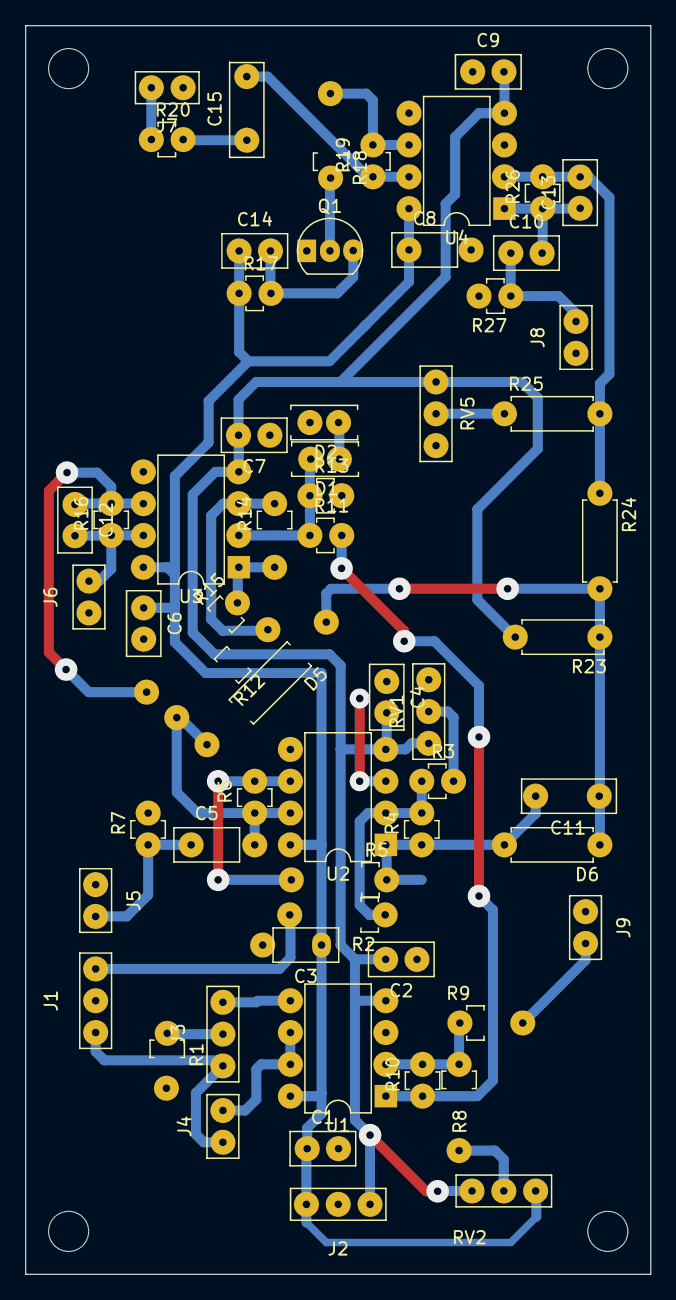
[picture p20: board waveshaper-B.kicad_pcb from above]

Board: 2 copper layers, 49.9 x 99.7 mm, 61 parts (0 on the bottom side), 35 nets.

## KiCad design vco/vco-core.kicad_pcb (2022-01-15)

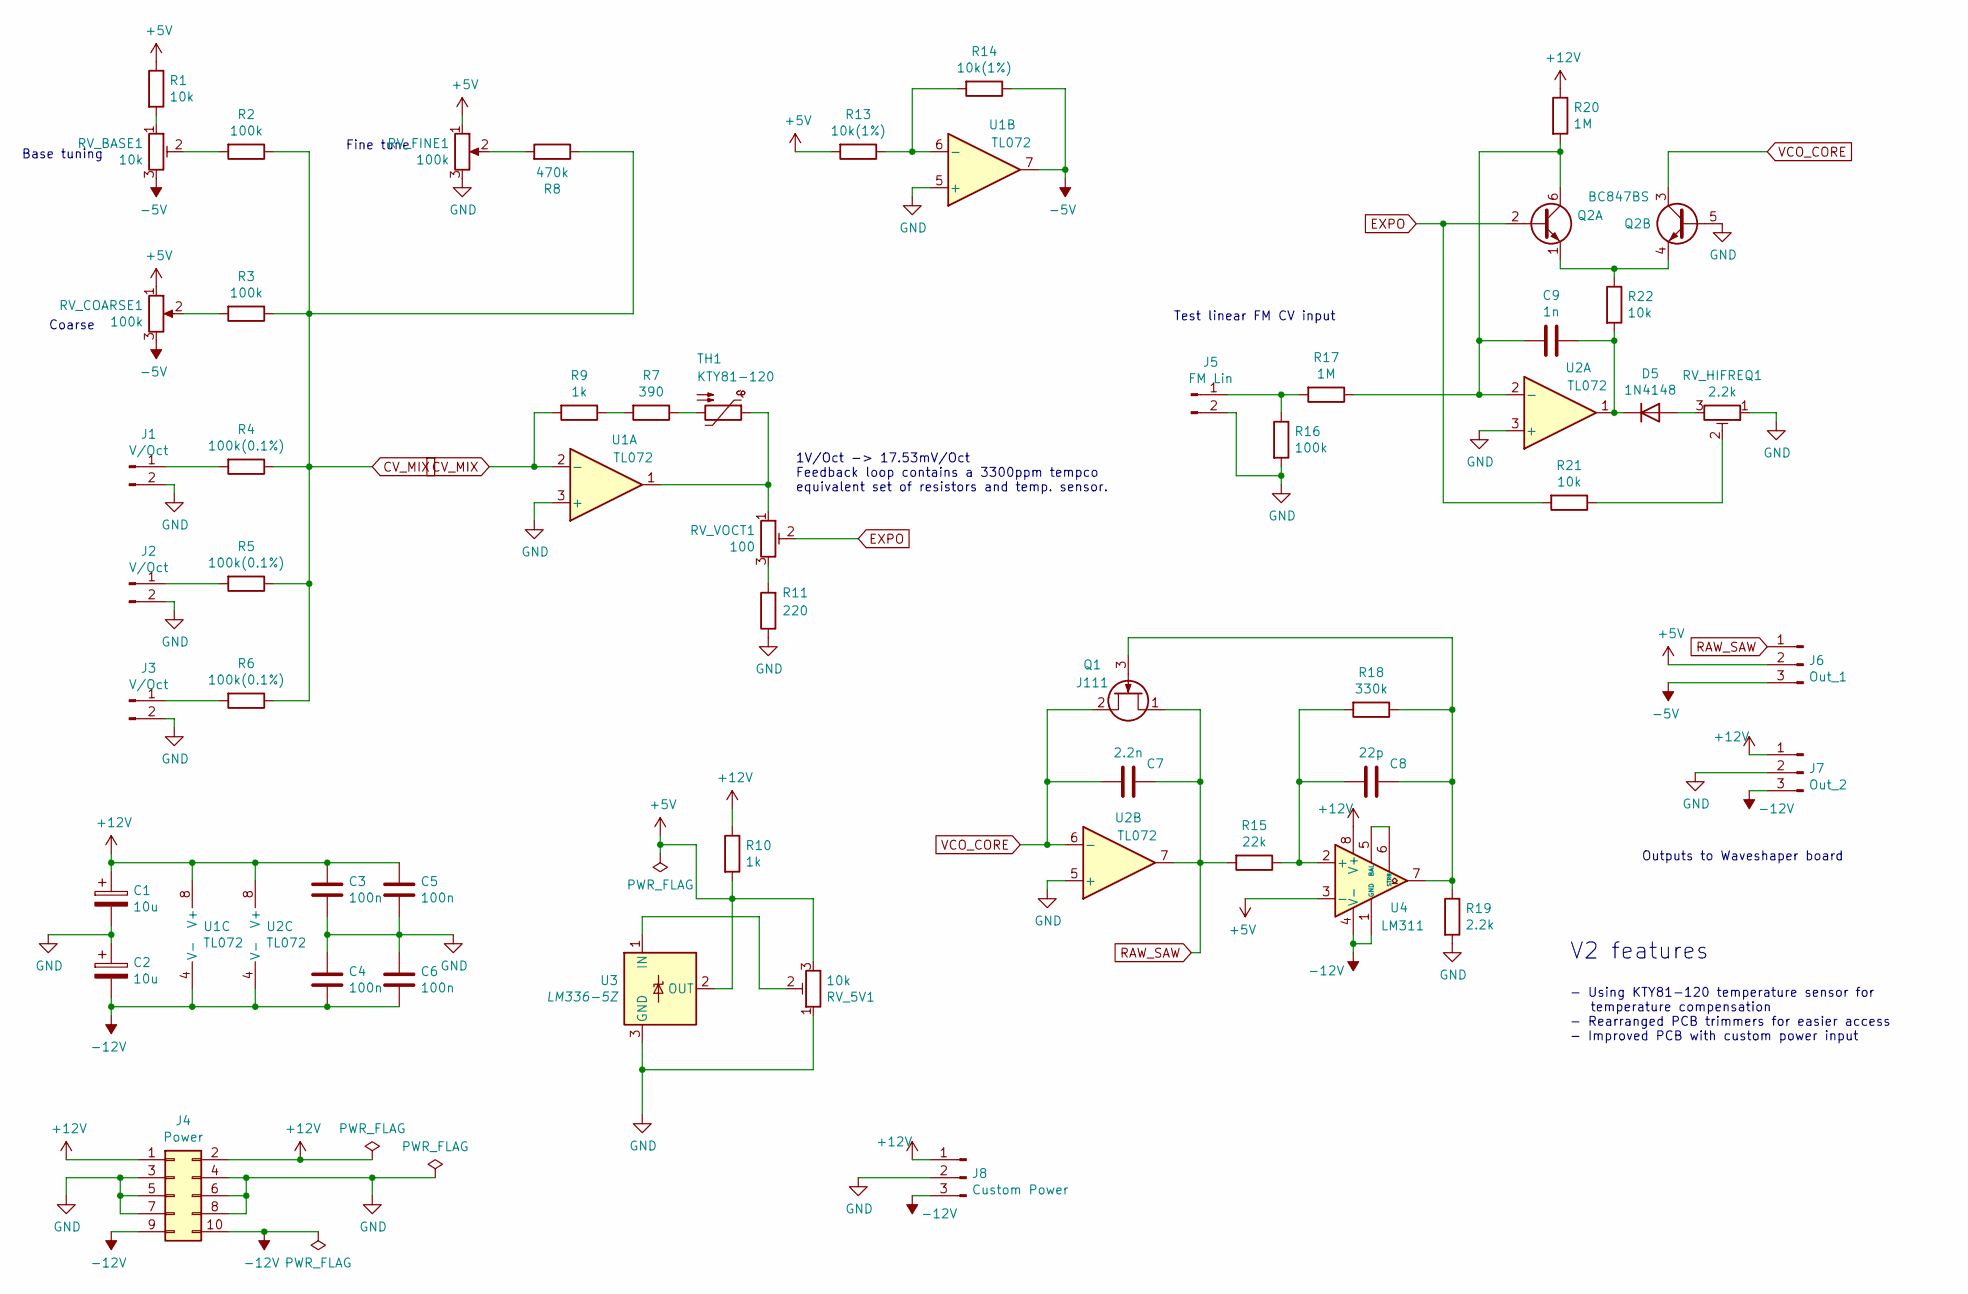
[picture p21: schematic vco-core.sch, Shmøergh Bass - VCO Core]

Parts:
C1, C2: 10u; CP_Radial_D5.0mm_P2.50mm
C3, C4, C5, C6: 100n; C_Disc_D5.0mm_W2.5mm_P2.50mm
C7: 2.2n; C_Disc_D5.0mm_W2.5mm_P2.50mm
C8: 22p; C_Disc_D5.0mm_W2.5mm_P2.50mm
C9: 1n; C_Disc_D5.0mm_W2.5mm_P2.50mm
D5: 1N4148; D_Axial-Vertical
J1, J2, J3: V/Oct; NSL25_01x02_Vertical
J4: Power; Eurorack_Power_Supply
J5: FM Lin; NSL25_01x02_Vertical
J6: Out_1; NSL25_01x03_Vertical
J7: Out_2; NSL25_01x03_Vertical
J8: Custom Power; NSL25_01x03_Vertical
Q1: J111; TO-92_Inline
Q2: BC847BS; SOT-363_SC-70-6
R1, R21, R22: 10k; R_Axial_Vertical
R2, R3, R16: 100k; R_Axial_Vertical
R4, R5, R6: 100k(0.1%); R_Axial_Vertical
R7: 390; R_Axial_Vertical
R8: 470k; R_Axial_Vertical
R9, R10: 1k; R_Axial_Vertical
R11: 220; R_Axial_Vertical
R13, R14: 10k(1%); R_Axial_Vertical
R15: 22k; R_Axial_Vertical
R17, R20: 1M; R_Axial_Vertical
R18: 330k; R_Axial_Vertical
R19: 2.2k; R_Axial_Vertical
RV_5V1: 10k; PinOut_01x03
RV_BASE1: 10k; PinOut_01x03
RV_COARSE1: 100k; NSL25_01x03_Vertical
RV_FINE1: 100k; NSL25_01x03_Vertical
RV_HIFREQ1: 2.2k; PinOut_01x03
RV_VOCT1: 100; PinOut_01x03
TH1: KTY81-120; R_Axial_DIN0207_L6.3mm_D2.5mm_P7.62mm_Horizontal
U1, U2: TL072; DIP-8_W7.62mm
U3: LM336-5Z; TO-92_Inline
U4: LM311; DIP-8_W7.62mm

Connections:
+5V: J6.2, R1.1, R10.2, R13.2, RV_5V1.3, RV_COARSE1.1, RV_FINE1.1, U3.2 (OUT), U4.3 (-)
+12V: C1.1, C3.1, C5.1, J4.1, J4.2, J7.1, J8.1, R10.1, R20.1, U1.8 (V+), U2.8 (V+), U4.8 (V+)
-5V: J6.3, R14.1, RV_BASE1.3, RV_COARSE1.3, U1.7
-12V: C2.2, C4.2, C6.2, J4.9, J4.10, J7.3, J8.3, U1.4 (V-), U2.4 (V-), U4.1 (GND), U4.4 (V-)
CV_MIX: R2.1, R3.1, R4.1, R5.1, R6.1, R8.1, R9.2, U1.2 (-)
EXPO: Q2.2 (B1), R21.2, RV_VOCT1.2
GND: C1.2, C2.1, C3.2, C4.1, C5.2, C6.1, J1.2, J2.2, J3.2, J4.3, J4.4, J4.5, J4.6, J4.7, J4.8, J5.2, J7.2, J8.2, Q2.5 (B2), R11.1, R16.2, R19.2, RV_5V1.1, RV_FINE1.3, RV_HIFREQ1.1, U1.3 (+), U1.5 (+), U2.3 (+), U2.5 (+), U3.3 (GND)
unnamed: C8.1, Q1.3 (G), R18.1, R19.1, U4.7
unnamed: C8.2, R15.1, R18.2, U4.2 (+)
unnamed: C9.1, D5.1 (K), R22.2, U2.1
unnamed: C9.2, Q2.6 (C1), R17.1, R20.2, U2.2 (-)
unnamed: D5.2 (A), RV_HIFREQ1.3
unnamed: J1.1, R4.2
unnamed: J2.1, R5.2
unnamed: J3.1, R6.2
unnamed: J5.1, R16.1, R17.2
unnamed: Q2.1 (E1), Q2.4 (E2), R22.1
unnamed: R1.2, RV_BASE1.1
unnamed: R2.2, RV_BASE1.2
unnamed: R3.2, RV_COARSE1.2
unnamed: R7.1, TH1.2
unnamed: R7.2, R9.1
unnamed: R8.2, RV_FINE1.2
unnamed: R11.2, RV_VOCT1.3
unnamed: R13.1, R14.2, U1.6 (-)
unnamed: R21.1, RV_HIFREQ1.2
unnamed: RV_5V1.2, U3.1 (IN)
unnamed: RV_VOCT1.1, TH1.1, U1.1
unnamed: U4.5 (BAL), U4.6 (STRB)
RAW_SAW: C7.1, J6.1, Q1.1 (D), R15.2, U2.7
VCO_CORE: C7.2, Q1.2 (S), Q2.3 (C2), U2.6 (-)

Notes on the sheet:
Coarse
Base tuning
Fine tune
Outputs to Waveshaper board
Test linear FM CV input
V2 features
- Using KTY81-120 temperature sensor for temperature compensation - Rearranged PCB trimmers for easier access - Improved PCB with custom power input
1V/Oct -> 17.53mV/Oct Feedback loop contains a 3300ppm tempco equivalent set of resistors and temp. sensor.

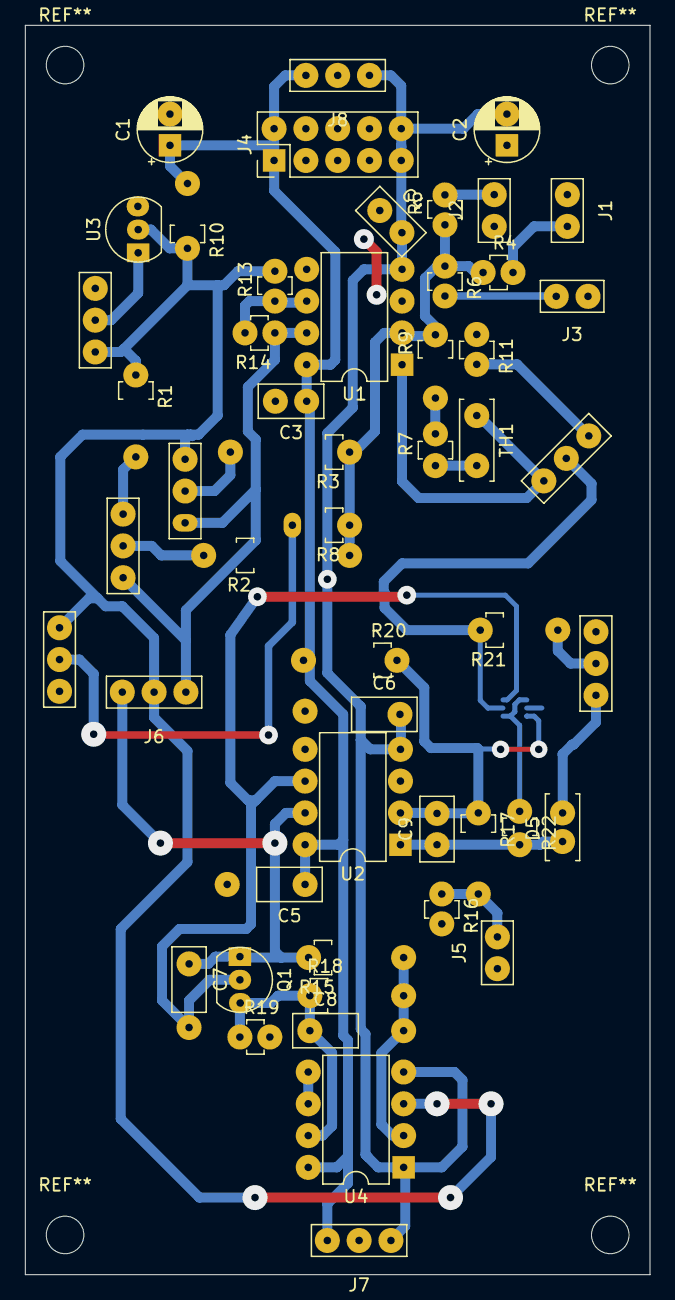
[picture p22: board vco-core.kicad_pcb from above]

Board: 2 copper layers, 49.9 x 99.8 mm, 52 parts (1 on the bottom side), 31 nets.

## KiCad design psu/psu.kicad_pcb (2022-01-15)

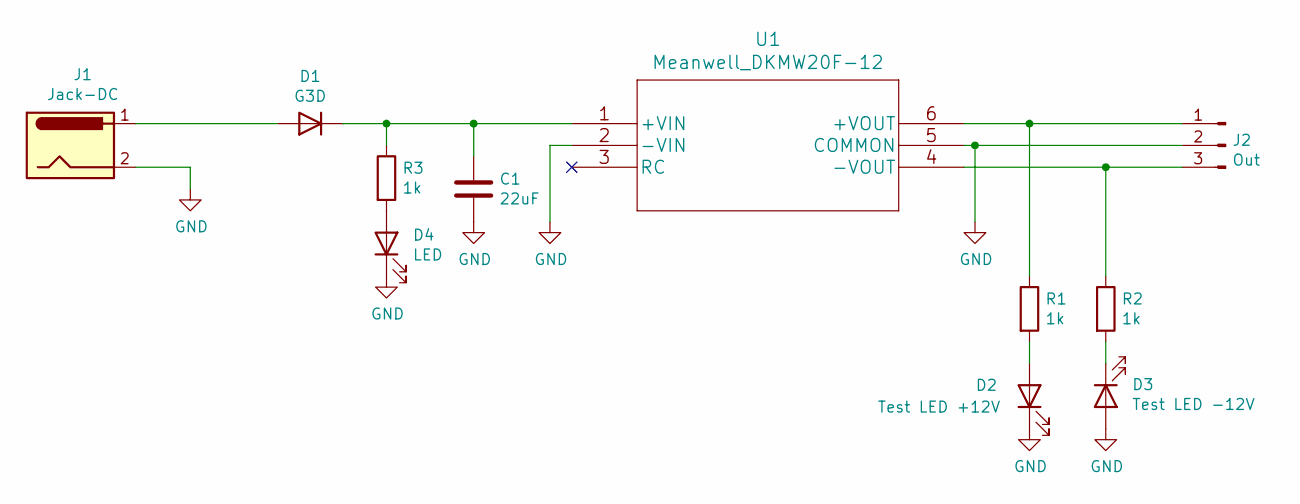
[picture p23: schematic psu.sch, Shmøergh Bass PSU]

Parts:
C1: 22uF; CP_Radial_D5.0mm_P2.50mm
D1: G3D; D_Axial
D2: Test LED +12V; NSL25_01x02_Vertical
D3: Test LED -12V; NSL25_01x02_Vertical
D4: LED; NSL25_01x02_Vertical
J1: Jack-DC; NSL25_01x02_Vertical
J2: Out; NSL25_01x03_Vertical
R1, R2, R3: 1k; R_Axial_DIN0207_L6.3mm_D2.5mm_P7.62mm_Horizontal
U1: Meanwell_DKMW20F-12; Meanwell_DKMWx0F_TopView

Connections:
GND: C1.2, D2.1 (K), D3.2 (A), D4.1 (K), J1.2, J2.2, U1.2 (-VIN), U1.5 (COMMON)
unnamed: C1.1, D1.1 (K), R3.1, U1.1 (+VIN)
unnamed: D1.2 (A), J1.1
unnamed: D2.2 (A), R1.2
unnamed: D3.1 (K), R2.2
unnamed: D4.2 (A), R3.2
unnamed: J2.1, R1.1, U1.6 (+VOUT)
unnamed: J2.3, R2.1, U1.4 (-VOUT)

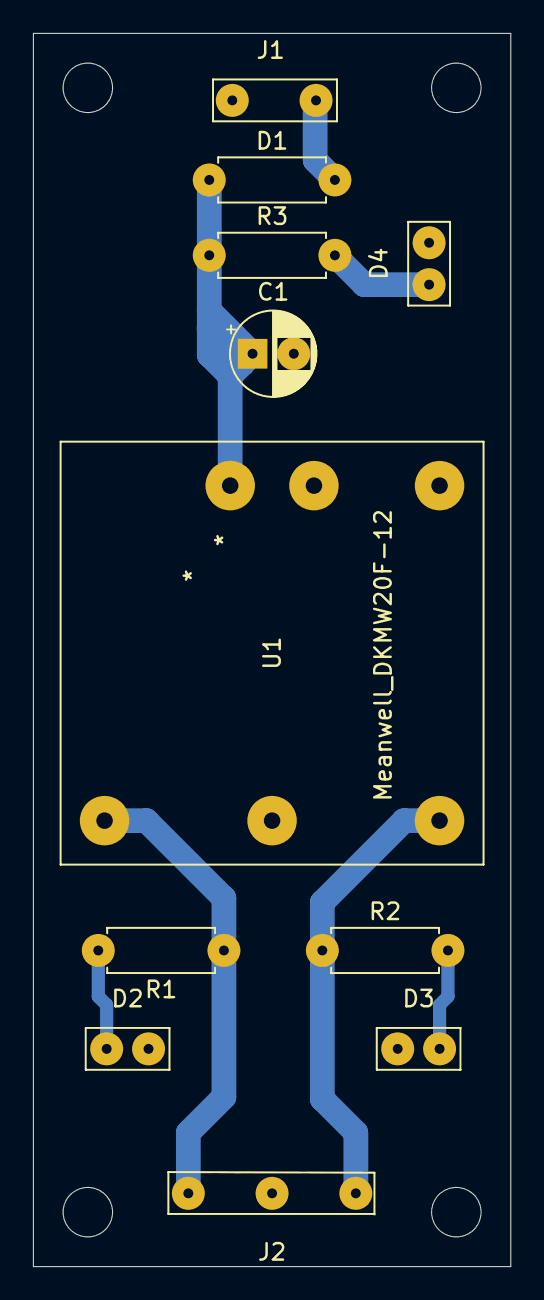
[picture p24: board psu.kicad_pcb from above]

Board: 2 copper layers, 29.0 x 74.8 mm, 11 parts (0 on the bottom side), 8 nets.

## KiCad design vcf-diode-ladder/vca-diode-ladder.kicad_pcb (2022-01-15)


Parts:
C1: 1u; C_Foil_P5.48mm
C2, C3, C4, C5, C6: 1n; C_Foil_P5.48mm
C7: 10n; C_Foil_P5.48mm
C8, C9: 10u; CP_Radial_D5.0mm_P2.50mm
C10, C11, C12, C13: 100n; C_Disc_D5.0mm_W2.5mm_P2.50mm
C14: 1u (film); C_Foil_P5.48mm
C15, C16, C17: 47p; C_Disc_D5.0mm_W2.5mm_P2.50mm
D1, D2, D3, D4, D5, D6, D7, D8, D9, D10, D11: 1N4148; D_Axial-Vertical
J1: Input; JT_A25_01x02_Vertical
J2, J6: CV; JT_A25_01x02_Vertical
J3: Output; JT_A25_01x02_Vertical
J4: Eurorack Power; Eurorack_Power_Supply
J5: Custom Power; NSL25_01x03_Vertical
R1, R4, R17, R23: 47k; R_Axial_Vertical
R2: 68k; R_Axial_Vertical
R3: 200k; R_Axial_Vertical
R5, R7, R8, R9, R10, R11, R12, R13: 33k; R_Axial_Vertical
R6, R20: 680; R_Axial_Vertical
R14, R15: 2k; R_Axial_Vertical
R16: 1k; R_Axial_Vertical
R18: 100k; R_Axial_Vertical
R19: 1M; R_Axial_Vertical
RV_CUTOFF1: 100k; JT_A25_01x03_Vertical
RV_CV1, RV_CV11: 100k; JT_A25_01x03_Vertical
RV_CV_LIMIT1: 10k; TrimPot_Vertical
RV_DRIVE1: 10k; JT_A25_01x03_Vertical
RV_RESONANCE1: 100k; JT_A25_01x03_Vertical
RV_RESO_GAIN1: 100k; TrimPot_Vertical
U1, U2: TL074; DIP-14_W7.62mm

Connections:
+12V: C8.1, C10.1, C12.1, J4.1, J4.2, J5.1, RV_CUTOFF1.1, U1.4 (V+), U2.4 (V+)
-12V: C9.2, C11.2, C13.2, J4.9, J4.10, J5.3, U1.11 (V-), U2.11 (V-)
CV: D3.1 (K), R8.2, R10.2
GND: C3.2, C4.2, C5.2, C7.2, C8.2, C9.1, C10.2, C11.1, C12.2, C13.1, J1.2, J2.2, J3.2, J4.3, J4.4, J4.5, J4.6, J4.7, J4.8, J5.2, J6.2, R3.2, R4.2, R6.2, R11.2, R19.1, RV_CUTOFF1.3, RV_CV1.3, RV_CV11.3, RV_CV_LIMIT1.1, RV_CV_LIMIT1.2, RV_DRIVE1.3, RV_RESONANCE1.1, RV_RESO_GAIN1.1, RV_RESO_GAIN1.2, U1.10 (+), U2.10 (+)
LADDER_N: D9.1 (K), R13.1, R15.1
LADDER_P: D4.2 (A), R12.1, R14.1
unnamed: C1.1, RV_DRIVE1.2
unnamed: C1.2, R3.1, R5.2
unnamed: C2.1, D4.1 (K), D5.2 (A)
unnamed: C2.2, C6.2, C7.1, R20.2
unnamed: C3.1, D5.1 (K), D6.2 (A)
unnamed: C4.1, D6.1 (K), D7.2 (A), U2.3 (+)
unnamed: C5.1, D7.1 (K), D8.2 (A)
unnamed: C6.1, D8.1 (K), D9.2 (A)
unnamed: C14.1, J3.1, R19.2
unnamed: C14.2, R17.1, U2.8
unnamed: C15.1, C15.2, D3.2 (A), U1.6 (-), U1.7
unnamed: C16.1, R14.2, U1.14
unnamed: C16.2, R7.1, R12.2, U1.13 (-)
unnamed: C17.1, R15.2, U1.8
unnamed: C17.2, R9.1, R10.1, R13.2, U1.9 (-)
unnamed: D1.1 (K), D2.2 (A)
unnamed: D1.2 (A), R1.1, R2.1, R4.1, R23.1, U1.5 (+)
unnamed: D2.1 (K), RV_CV_LIMIT1.3
unnamed: D10.1 (K), D11.2 (A), R18.1, RV_RESO_GAIN1.3, U2.13 (-)
unnamed: D10.2 (A), D11.1 (K), R18.2, R20.1, U2.14
unnamed: J1.1, RV_DRIVE1.1
unnamed: J2.1, RV_CV11.1
unnamed: J6.1, RV_CV1.1
unnamed: R1.2, RV_CV11.2
unnamed: R2.2, RV_CUTOFF1.2
unnamed: R5.1, R6.1, U1.3 (+)
unnamed: R7.2, R9.2, U1.1, U1.2 (-)
unnamed: R8.1, R11.1, U1.12 (+)
unnamed: R16.1, R17.2, U2.9 (-)
unnamed: R23.2, RV_CV1.2
unnamed: RV_RESONANCE1.2, U2.12 (+)
OUT_STAGE: R16.2, RV_RESONANCE1.3, U2.1, U2.2 (-)

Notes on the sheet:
To be improved: passive CV mixer to active
To be improved: the resonance path picks up a lot of hum, especially if RV_RESONANCE pot is connected via wires.


Board: 2 copper layers, 49.9 x 100.0 mm, 64 parts (0 on the bottom side), 38 nets.

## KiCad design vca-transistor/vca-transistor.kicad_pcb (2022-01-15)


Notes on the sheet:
VCA 1: Used for voice VCA 2: Used to control global LFO amount. Can be connected to modwheel of keyboard.


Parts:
C1, C2: 100n; C_Disc_D5.0mm_W2.5mm_P2.50mm
C3: 47p; C_Disc_D5.0mm_W2.5mm_P2.50mm
D1: 1N4148; D_Axial-Vertical
J1: MOD_CV_IN; NSL25_01x02_Vertical
J2: CV_IN; NSL25_01x02_Vertical
J3: SIGNAL_IN; NSL25_01x02_Vertical
J4: AUDIO_OUT; NSL25_01x02_Vertical
Q1, Q2: 2N3904; TO-92_Inline
R1: 470k; R_Axial_Vertical
R2: 150k; R_Axial_Vertical
R3: 240k; R_Axial_Vertical
R4: 33k; R_Axial_Vertical
R5, R8, R9: 100k; R_Axial_Vertical
R6, R12: 220; R_Axial_Vertical
R10, R11: 10k; R_Axial_Vertical
R13, R15: 680k; R_Axial_Vertical
R14: 1M; R_Axial_Vertical
R16: 1k; R_Axial_Vertical
RV_CV_BIAS1: 100k; TrimPot_Vertical
RV_DC_BIAS1: 100k; TrimPot_Vertical
RV_IC1: 10k; TrimPot_Vertical
RV_IC_COMP1: 2.2k; TrimPot_Vertical
U1: TL072; DIP-8_W7.62mm

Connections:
+12V: C1.1, RV_CV_BIAS1.3, RV_DC_BIAS1.3, RV_IC_COMP1.2, U1.8 (V+); also elsewhere on the board
-12V: C2.2, RV_DC_BIAS1.1, U1.4 (V-); also elsewhere on the board
GND: C1.2, C2.1, D1.2 (A), J1.2, J2.2, J3.2, J4.2, R6.2, R12.2, R13.2, RV_CV_BIAS1.1, U1.3 (+); also elsewhere on the board
unnamed: C3.1, R15.1, R16.2, U1.7
unnamed: C3.2, R10.1, R15.2, U1.6 (-)
unnamed: D1.1 (K), R4.1, RV_IC1.1, U1.1
unnamed: J1.1, R2.2
unnamed: J2.1, R1.2
unnamed: J3.1, R5.2
unnamed: J4.1, R16.1
unnamed: Q1.1 (E), Q2.1 (E), RV_IC1.2, RV_IC1.3
unnamed: Q1.2 (B), R5.1, R6.1
unnamed: Q1.3 (C), R8.2, R10.2
unnamed: Q2.2 (B), R12.1, R14.2
unnamed: Q2.3 (C), R9.2, R11.2
unnamed: R1.1, R2.1, R3.1, R4.2, U1.2 (-)
unnamed: R3.2, RV_CV_BIAS1.2
unnamed: R8.1, RV_IC_COMP1.3
unnamed: R9.1, RV_IC_COMP1.1
unnamed: R11.1, R13.1, U1.5 (+)
unnamed: R14.1, RV_DC_BIAS1.2

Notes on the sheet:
Matched transistors
+/-5V Coming from the mod matrix
0-8V Only for VCA 1
Voice VCA
VCA for the main output. Chain: VCO > Mixer > Filter > VCA (controlled by ADSR 1) > Out stage
Should be around 5.6k


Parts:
C4, C5: 10u; CP_Radial_D5.0mm_P2.50mm
J9: Custom Power; NSL25_01x03_Vertical
J10: Eurorack Power; Eurorack_Power_Supply

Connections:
+12V: C4.1, J9.1, J10.1, J10.2; also elsewhere on the board
-12V: C5.2, J9.3, J10.9, J10.10; also elsewhere on the board
GND: C4.2, C5.1, J9.2, J10.3, J10.4, J10.5, J10.6, J10.7, J10.8; also elsewhere on the board


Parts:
C6, C7: 100n; C_Disc_D5.0mm_W2.5mm_P2.50mm
C8: 47p; C_Disc_D5.0mm_W2.5mm_P2.50mm
D2: 1N4148; D_Axial-Vertical
J5: LFO IN; NSL25_01x02_Vertical
J6: LFO_OUT; NSL25_01x02_Vertical
Q3, Q4: 2N3904; TO-92_Inline
R17: 4.7k; R_Axial_Vertical
R18: 240k; R_Axial_Vertical
R19: 200k; R_Axial_Vertical
R20: 33k; R_Axial_Vertical
R21, R24, R25: 100k; R_Axial_Vertical
R22, R28: 220; R_Axial_Vertical
R26, R27: 10k; R_Axial_Vertical
R29, R31: 680k; R_Axial_Vertical
R30: 1M; R_Axial_Vertical
R32: 1k; R_Axial_Vertical
RV_CV_BIAS2: 100k; TrimPot_Vertical
RV_DC_BIAS2: 100k; TrimPot_Vertical
RV_IC2: 10k; TrimPot_Vertical
RV_IC_COMP2: 2.2k; TrimPot_Vertical
RV_MANUAL1: 10k; NSL25_01x03_Vertical
U2: TL072; DIP-8_W7.62mm

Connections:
+12V: C6.1, R17.1, RV_CV_BIAS2.3, RV_DC_BIAS2.3, RV_IC_COMP2.2, U2.8 (V+); also elsewhere on the board
-12V: C7.2, RV_DC_BIAS2.1, U2.4 (V-); also elsewhere on the board
GND: C6.2, C7.1, D2.2 (A), J5.2, J6.2, R22.2, R28.2, R29.2, RV_CV_BIAS2.1, RV_MANUAL1.3, U2.3 (+); also elsewhere on the board
unnamed: C8.1, R31.1, R32.2, U2.7
unnamed: C8.2, R26.1, R31.2, U2.6 (-)
unnamed: D2.1 (K), R20.1, RV_IC2.1, U2.1
unnamed: J5.1, R21.2
unnamed: J6.1, R32.1
unnamed: Q3.1 (E), Q4.1 (E), RV_IC2.2, RV_IC2.3
unnamed: Q3.2 (B), R21.1, R22.1
unnamed: Q3.3 (C), R24.2, R26.2
unnamed: Q4.2 (B), R28.1, R30.2
unnamed: Q4.3 (C), R25.2, R27.2
unnamed: R17.2, RV_MANUAL1.1
unnamed: R18.1, R19.1, R20.2, U2.2 (-)
unnamed: R18.2, RV_CV_BIAS2.2
unnamed: R19.2, RV_MANUAL1.2
unnamed: R24.1, RV_IC_COMP2.3
unnamed: R25.1, RV_IC_COMP2.1
unnamed: R27.1, R29.1, U2.5 (+)
unnamed: R30.1, RV_DC_BIAS2.2

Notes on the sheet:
Matched transistors
Jack as switch here to enable modwheel connection
Only for VCA 2
LFO VCA
The purpose of this VCA is to let the modwheel control the amount of global LFO. Alternatively there’s a slide pot that can be used instead of the modwheel.
About 5.6k value


Board: 2 copper layers, 49.8 x 99.9 mm, 63 parts (0 on the bottom side), 39 nets.

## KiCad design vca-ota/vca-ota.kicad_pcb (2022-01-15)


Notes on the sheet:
VCA 1: Used for voice VCA 2: Used to control global LFO amount. Can be connected to modwheel of keyboard.


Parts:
C4, C5: 10u; CP_Radial_D5.0mm_P2.50mm
J9: Custom Power; NSL25_01x03_Vertical
J10: Eurorack Power; Eurorack_Power_Supply

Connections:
+12V: C4.1, J9.1, J10.1, J10.2; also elsewhere on the board
-12V: C5.2, J9.3, J10.9, J10.10; also elsewhere on the board
GND: C4.2, C5.1, J9.2, J10.3, J10.4, J10.5, J10.6, J10.7, J10.8; also elsewhere on the board


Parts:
C1, C2: 100n; C_Disc_D5.0mm_W2.5mm_P2.50mm
C3: 470n; C_Disc_D5.0mm_W2.5mm_P2.50mm
C6: 1n; C_Disc_D5.0mm_W2.5mm_P2.50mm
C11: 47p; C_Disc_D5.0mm_W2.5mm_P2.50mm
D1: 1N4148; D_Axial-Vertical
J1: ADSR_CV; NSL25_01x02_Vertical
J2: MOD_MATRIX_CV; NSL25_01x02_Vertical
J3: INPUT; NSL25_01x02_Vertical
J4: OUTPUT; NSL25_01x02_Vertical
Q1: 2N3906; TO-92_Inline_Wide
R1: 240k; R_Axial_Vertical
R2: 330k; R_Axial_Vertical
R3: 100k; R_Axial_Vertical
R4, R5: 620; R_Axial_Vertical
R6, R9: 33k; R_Axial_Vertical
R7: 6.8k; R_Axial_Vertical
R8, R10: 1k; R_Axial_Vertical
R13: 680k; R_Axial_Vertical
RV_ADSR_LEVEL1: 100k; TrimPot_Vertical
RV_CV_BIAS1: 10k; TrimPot_Vertical
U1: TL072; DIP-8_W7.62mm
U2: LM13700; DIP-16_W7.62mm

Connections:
+12V: C1.1, RV_CV_BIAS1.1, U1.8 (V+), U2.11 (V+); also elsewhere on the board
-12V: C2.2, RV_CV_BIAS1.3, U1.4 (V-), U2.6 (V-); also elsewhere on the board
GND: C1.2, C2.1, J1.2, J2.2, J3.2, J4.2, R4.2, R5.2, R8.1, U1.3 (+), U1.5 (+), U2.7; also elsewhere on the board
unnamed: C3.1, R3.2
unnamed: C3.2, J3.1
unnamed: C6.1, D1.2 (A), Q1.2 (B), U1.1
unnamed: C6.2, D1.1 (K), R1.1, R2.1, R6.2, R13.1, U1.2 (-)
unnamed: C11.1, R9.1, R10.2, U1.7
unnamed: C11.2, R9.2, U1.6 (-), U2.5
unnamed: J1.1, RV_ADSR_LEVEL1.1
unnamed: J2.1, R1.2
unnamed: J4.1, R10.1
unnamed: Q1.1 (E), R6.1, R8.2
unnamed: Q1.3 (C), R7.1
unnamed: R2.2, RV_ADSR_LEVEL1.2, RV_ADSR_LEVEL1.3
unnamed: R3.1, R4.1, U2.4 (-)
unnamed: R5.1, U2.3 (+)
unnamed: R7.2, U2.1
unnamed: R13.2, RV_CV_BIAS1.2

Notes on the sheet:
0-8V
-5 – 8V
+/-5V
Voice VCA
CV from the Mod mixer. This can either be +/-5V (e.g. LFO or VCO output) or 0-8V (filter ADSR). Negative values shouldn’t be an issue because Q1 would be closed in that case, so the input should be prepared to 0-8V.
0-500uA
Calculations are in the LFO sheet.


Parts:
C7, C8: 100n; C_Disc_D5.0mm_W2.5mm_P2.50mm
C9: 470n; C_Disc_D5.0mm_W2.5mm_P2.50mm
C10: 1n; C_Disc_D5.0mm_W2.5mm_P2.50mm
C12: 47p; C_Disc_D5.0mm_W2.5mm_P2.50mm
D2: 1N4148; D_Axial-Vertical
J5: INPUT; NSL25_01x02_Vertical
J6: OUTPUT; NSL25_01x02_Vertical
Q2: 2N3906; TO-92_Inline_Wide
R11: 15k; R_Axial_Vertical
R12: 240k; R_Axial_Vertical
R14: 100k; R_Axial_Vertical
R15, R16: 620; R_Axial_Vertical
R17, R20: 33k; R_Axial_Vertical
R18: 6.8k; R_Axial_Vertical
R19, R21: 1k; R_Axial_Vertical
R22: 680k; R_Axial_Vertical
RV_CV_BIAS2: 10k; TrimPot_Vertical
RV_MOD_AMOUNT1: 10k; NSL25_01x03_Vertical
U2: LM13700; DIP-16_W7.62mm
U3: TL072; DIP-8_W7.62mm

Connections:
+12V: C7.1, R11.1, RV_CV_BIAS2.1, U3.8 (V+); also elsewhere on the board
-12V: C8.2, RV_CV_BIAS2.3, U3.4 (V-); also elsewhere on the board
GND: C7.2, C8.1, J5.2, J6.2, R15.2, R16.2, R19.1, RV_MOD_AMOUNT1.3, U2.10, U3.3 (+), U3.5 (+); also elsewhere on the board
unnamed: C9.1, R14.2
unnamed: C9.2, J5.1
unnamed: C10.1, D2.2 (A), Q2.2 (B), U3.1
unnamed: C10.2, D2.1 (K), R12.1, R17.2, R22.1, U3.2 (-)
unnamed: C12.1, R20.1, R21.2, U3.7
unnamed: C12.2, R20.2, U2.12, U3.6 (-)
unnamed: J6.1, R21.1
unnamed: Q2.1 (E), R17.1, R19.2
unnamed: Q2.3 (C), R18.1
unnamed: R11.2, RV_MOD_AMOUNT1.1
unnamed: R12.2, RV_MOD_AMOUNT1.2
unnamed: R14.1, R15.1, U2.13 (-)
unnamed: R16.1, U2.14 (+)
unnamed: R18.2, U2.16
unnamed: R22.2, RV_CV_BIAS2.2

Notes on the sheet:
0-5V
+/-5V
This is the slider pot on the frontpanel of the synth. It’s the same purpose as the modwheel on controllers.
Jack as switch here to enable direct modwheel connection from controller.
LFO VCA
The purpose of this VCA is to be able to controll the LFO amount via either the mod slider pot on the synth or via the modwheel of a controller.
0-15uA
0-495uA
Ie = 0-510uA
Iabc = Ic = Ie = 0-510uA
Safety resistor, max Iabc = 12V / 6.8k = 1.76mA (in case transistor’s collector voltage = 12V)
IOut(pp) = (q/2kT) * Iabc * Vin = 19.2 * 500uA * 61.6mV = 591uA
Vin(pp) = 10V * 620 / 100k + 620 = 61.6mV (10V => +/-5V)
Vout(pp) = 18k * 591uA = 10,6V
Ve(max) = -IR17 * R17 = -0.495V
Transistor’s reverse bias safety diode in case of negative CV inputs


Board: 2 copper layers, 49.8 x 99.9 mm, 53 parts (0 on the bottom side), 34 nets.

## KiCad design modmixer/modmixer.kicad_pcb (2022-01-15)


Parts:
C1, C2: 22p; C_Disc_D5.0mm_W2.5mm_P2.50mm
C3, C4: 100n; C_Disc_D5.0mm_W2.5mm_P2.50mm
C5, C6: 10u; CP_Radial_D5.0mm_P2.50mm
J1: CV Mixer In 1; NSL25_01x02_Vertical
J2: CV Mixer In 2; NSL25_01x02_Vertical
J10: PwrO; NSL25_01x03_Vertical
J15: CV Mixer Out; NSL25_01x02_Vertical
J16: Power; NSL25_01x03_Vertical
J17: CV In (Default LFO); NSL25_01x02_Vertical
J18: Fine Tune VCO1; NSL25_01x02_Vertical
J19: Fine Tune VCO2; NSL25_01x02_Vertical
J20: Vibrato Out; NSL25_01x02_Vertical
R1, R2: 10k; R_Axial_Vertical
R3, R4, R5, R6, R11: 100k; R_Axial_Vertical
R7: 330k; R_Axial_Vertical
R8: 1k; R_Axial_Vertical
R9: 1M; R_Axial_Vertical
R10: 620k; R_Axial_Vertical
RV_CV_BALANCE1: 100k; NSL25_01x03_Vertical
RV_CV_LEVEL1: 100k; NSL25_01x03_Vertical
RV_FINE_TUNE1: 100k; NSL25_01x03_Vertical
RV_VIBRATO_LVL1: A50k; NSL25_01x03_Vertical
U1: TL072; DIP-8_W7.62mm

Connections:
+12V: C3.1, C5.1, J10.1, J16.1, R9.1, U1.8 (V+)
-12V: C4.2, C6.2, J10.3, J16.3, U1.4 (V-)
GND: C3.2, C4.1, C5.2, C6.1, J1.2, J2.2, J10.2, J15.2, J16.2, J17.2, J18.2, J19.2, J20.2, RV_CV_BALANCE1.2, RV_CV_LEVEL1.3, RV_FINE_TUNE1.3, RV_VIBRATO_LVL1.3, U1.3 (+), U1.5 (+)
unnamed: C1.1, R5.1, RV_CV_LEVEL1.1, U1.1
unnamed: C1.2, R3.1, R4.1, R5.2, U1.2 (-)
unnamed: C2.1, R7.1, R8.2, U1.7
unnamed: C2.2, R6.1, R7.2, U1.6 (-)
unnamed: J1.1, R2.2
unnamed: J2.1, R1.2
unnamed: J15.1, R8.1
unnamed: J17.1, RV_VIBRATO_LVL1.1
unnamed: J18.1, J19.1, R10.1
unnamed: J20.1, R11.1
unnamed: R1.1, R4.2, RV_CV_BALANCE1.3
unnamed: R2.1, R3.2, RV_CV_BALANCE1.1
unnamed: R6.2, RV_CV_LEVEL1.2
unnamed: R9.2, RV_FINE_TUNE1.1
unnamed: R10.2, RV_FINE_TUNE1.2
unnamed: R11.2, RV_VIBRATO_LVL1.2

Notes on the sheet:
CV Mixer
VCO Pitch CV


Board: 2 copper layers, 49.8 x 46.4 mm, 31 parts (0 on the bottom side), 19 nets.

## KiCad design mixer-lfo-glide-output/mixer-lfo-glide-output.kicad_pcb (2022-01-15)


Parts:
C10, C11: 10u; CP_Radial_D5.0mm_P2.50mm
J1: Eurorack Power; Eurorack_Power_Supply
J2: Custom Power; NSL25_01x03_Vertical

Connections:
+12V: C10.1, J1.1, J1.2, J2.1; also elsewhere on the board
-12V: C11.2, J1.9, J1.10, J2.3; also elsewhere on the board


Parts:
J3: Inputs 1-3; JT_A25_01x03_Vertical
J4: Inputs 4-6; JT_A25_01x03_Vertical
J22: Glide In; JT_A25_01x02_Vertical

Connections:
PITCH_IN: J22.1; also elsewhere on the board

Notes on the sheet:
Mixer inputs
Level pots are wired on panel, not present on PCB
Glide input


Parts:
J5: Line out; JT_A25_01x03_Vertical
J6: Eurorack out (10Vpp); JT_A25_01x02_Vertical
J7: Phones; JT_A25_01x03_Vertical
J8: Grounds; JT_A25_01x03_Vertical
J10: Tri From VCA; JT_A25_01x02_Vertical
J11, J16, J17, J18, J19, J21: LFO Square (5Vpp); JT_A25_01x02_Vertical
J12, J13, J14, J20: LFO Triangle (VCA); JT_A25_01x02_Vertical
J15: LFO Triangle (5Vpp); JT_A25_01x02_Vertical
J23: Glide Out; JT_A25_01x02_Vertical
J24: 10Vpp to VCA; JT_A25_01x02_Vertical
J25: From 10Vpp VCA; JT_A25_01x02_Vertical
R1: 1k; R_Axial_Vertical

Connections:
EURO_OUT: J6.1; also elsewhere on the board
FROM_VOICE_VCA: J25.1; also elsewhere on the board
LFO_SQR_OUT: J11.1, J16.1, J17.1, J18.1, J19.1, J21.1; also elsewhere on the board
LFO_TRI_OUT: J10.1, J12.1, J13.1, J14.1, J20.1
LINE_OUT: J5.1; also elsewhere on the board
unnamed: J5.2, R1.2
PHONES_OUT: J7.1, J7.2; also elsewhere on the board
PITCH_OUT: J23.1; also elsewhere on the board
TO_VOICE_VCA: J24.1; also elsewhere on the board
TRI_TO_VCA: J15.1; also elsewhere on the board

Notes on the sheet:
Mixer outs
Tip Ring Sleeve
Ring Sleeve
LFO outs
Glide out


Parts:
C1, C2, C3, C4: 100n; C_Disc_D5.0mm_W2.5mm_P2.50mm
C5, C6: 47p; C_Disc_D5.0mm_W2.5mm_P2.50mm
C7, C9: 22p; C_Disc_D5.0mm_W2.5mm_P2.50mm
C8: 10u; CP_Radial_D5.0mm_P2.50mm
D1, D2: 1N4148; D_Axial-Vertical
J9: Cap Bypass Jumper; PinOut_01x02
R2, R3, R4, R5, R6, R8, R9, R10, R13: 100k; R_Axial_Vertical
R7, R11, R14, R18, R19: 10k; R_Axial_Vertical
R12, R20: 1k; R_Axial_Vertical
R15: 33k; R_Axial_Vertical
R16, R17: 100; R_Axial_Vertical
RV_EXTERNAL_GAIN1: 100k; JT_A25_01x03_Vertical
RV_HEADP_VOL3: A50k; JT_A25_01x03_Vertical
RV_MAIN_VOL2: A50k; JT_A25_01x03_Vertical
U1: NE5532; DIP-8_W7.62mm
U2: TL074; DIP-14_W7.62mm

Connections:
+12V: C1.1, C3.1, D1.1 (K), U1.8 (V+), U2.4 (V+); also elsewhere on the board
-12V: C2.2, C4.2, D2.2 (A), U1.4 (V-), U2.11 (V-); also elsewhere on the board
EURO_OUT: R12.1; also elsewhere on the board
FROM_VOICE_VCA: RV_MAIN_VOL2.1; also elsewhere on the board
LINE_OUT: R20.1; also elsewhere on the board
unnamed: C5.1, R8.1, R9.2, U2.1
unnamed: C5.2, R2.1, R3.1, R4.1, R5.1, R6.1, R7.2, R8.2, U2.2 (-)
unnamed: C6.2, R9.1, R10.2, U2.6 (-)
unnamed: C7.1, C8.1, J9.2, R15.1, RV_HEADP_VOL3.1, U2.8
unnamed: C7.2, R13.1, R15.2, U2.9 (-)
unnamed: C8.2, J9.1, R18.2
unnamed: C9.1, D1.2 (A), D2.1 (K), R19.1, R20.2, U2.14
unnamed: C9.2, R18.1, R19.2, U2.13 (-)
unnamed: R7.1, RV_EXTERNAL_GAIN1.3
unnamed: R11.1, R14.2, U1.2 (-)
unnamed: R11.2, RV_HEADP_VOL3.2
unnamed: R12.2, R13.2, RV_MAIN_VOL2.2
unnamed: R14.1, R17.2, U1.1, U1.5 (+)
unnamed: R16.2, U1.6 (-), U1.7
PHONES_OUT: R16.1, R17.1; also elsewhere on the board
TO_VOICE_VCA: C6.1, R10.1, U2.7; also elsewhere on the board

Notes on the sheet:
Headphones volume
Square narrow pulse width makes the output center go off 0V. The 10u cap is most probably not needed, as everything (except for the external input) is AC coupled already.
Gain (max 10x)
Double buffer
Clamping


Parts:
C12, C13: 100n; C_Disc_D5.0mm_W2.5mm_P2.50mm
C14: 100n; C_Foil_P2.50mm
Q1: BC548; TO-92_Inline_Wide
R21, R22, R23, R24, R31: 100k; R_Axial_Vertical
R25: 10k; R_Axial_Vertical
R26, R27: 47k; R_Axial_Vertical
R32, R33: 1k; R_Axial_Vertical
RV_SPEED1: 10k; JT_A25_01x03_Vertical
RV_SQR_LEVEL1: 10k; TrimPot_Vertical
RV_TRI_LEVEL1: 10k; TrimPot_Vertical
U3: TL074; DIP-14_W7.62mm

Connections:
+12V: C12.1, RV_SPEED1.1, U3.4 (V+); also elsewhere on the board
-12V: C13.2, U3.11 (V-); also elsewhere on the board
LFO_SQR_OUT: R33.1; also elsewhere on the board
unnamed: C14.1, RV_TRI_LEVEL1.1, U3.1, U3.13 (-)
unnamed: C14.2, R21.1, R23.1, R24.1, U3.2 (-)
unnamed: Q1.1 (C), R23.2, R24.2
unnamed: Q1.2 (B), R25.2
unnamed: R21.2, R22.2, RV_SPEED1.2
unnamed: R22.1, R31.1, U3.3 (+)
unnamed: R25.1, R27.1, RV_SQR_LEVEL1.1, U3.14
unnamed: R26.1, R27.2, U3.12 (+)
unnamed: R32.2, U3.8, U3.9 (-)
unnamed: R33.2, U3.6 (-), U3.7
unnamed: RV_SQR_LEVEL1.2, U3.5 (+)
unnamed: RV_TRI_LEVEL1.2, U3.10 (+)
TRI_TO_VCA: R32.1; also elsewhere on the board

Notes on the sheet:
Output level should be cca. 5V
Foil cap


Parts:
C15, C16: 100n; C_Disc_D5.0mm_W2.5mm_P2.50mm
C17: 1u; CP_Radial_D5.0mm_P2.50mm
R28: 100k; R_Axial_Vertical
R29: 100; R_Axial_Vertical
R30: 1k; R_Axial_Vertical
RV_GLIDE1: A500k; JT_A25_01x03_Vertical
U4: TL072; DIP-8_W7.62mm

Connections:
+12V: C15.1, U4.8 (V+); also elsewhere on the board
-12V: C16.2, U4.4 (V-); also elsewhere on the board
unnamed: C17.1, RV_GLIDE1.2, RV_GLIDE1.3, U4.5 (+)
unnamed: R29.1, RV_GLIDE1.1
unnamed: R29.2, U4.1, U4.2 (-)
unnamed: R30.2, U4.6 (-), U4.7
PITCH_IN: R28.1, U4.3 (+); also elsewhere on the board
PITCH_OUT: R30.1; also elsewhere on the board

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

Board: 2 copper layers, 74.9 x 99.9 mm, 89 parts (0 on the bottom side), 50 nets.

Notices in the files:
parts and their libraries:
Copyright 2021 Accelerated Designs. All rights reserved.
